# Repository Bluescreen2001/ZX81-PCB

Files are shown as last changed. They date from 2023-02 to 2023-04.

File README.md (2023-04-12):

# ZX81-PCB

Recreation of the original ZX81 Issue1 PCB with rounded traces, and the WespiNano, a tiny version of the Wespi.

## DISCLAIMER:

This is for personal use only. You may not sell this design without contacting me.

## Description:

The Sinclair ZX81 was one of the first home computers. There are several PCB versions out there, but the film for the first version was created 
manually with clear foil and stickers and pen. This first version (Issue One) is rare but it is "the original" with non CAD like rounded traces.

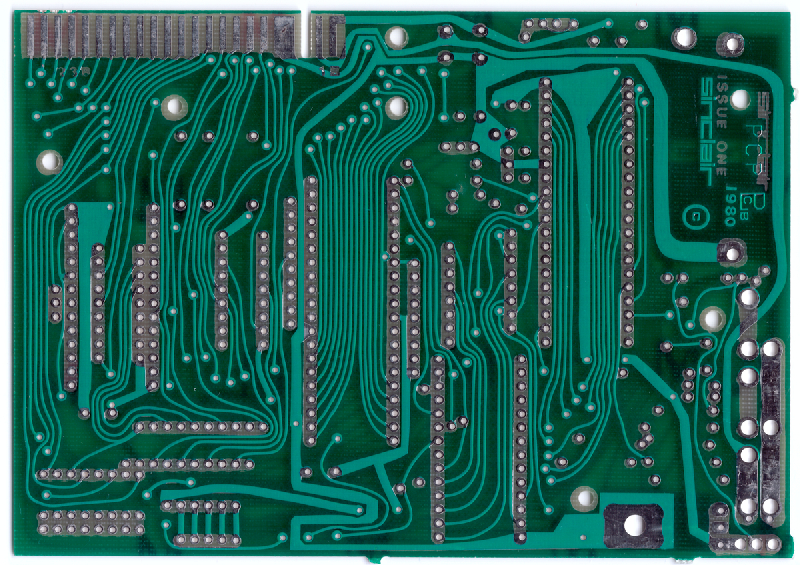
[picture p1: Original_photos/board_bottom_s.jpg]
Original PCB


One day some people from the German Sinclair [ZX81 forum](https://forum.tlienhard.com) diskussed how this PCB can be recreated.
So I took a photo from front and back side of the PCB with a scanner, put this as a background images in my CAD application and redraw all the traces. 
The resulting DXF file was then imported into EAGLE and than mapped to an EAGLE schematic, so I get a consistent EAGLE project. After some fine tuning 
I got a PCB design which was nearly like the original.

After some diskussions we decided to create a slightly altered version with some "modern" features. See the following chapter ...

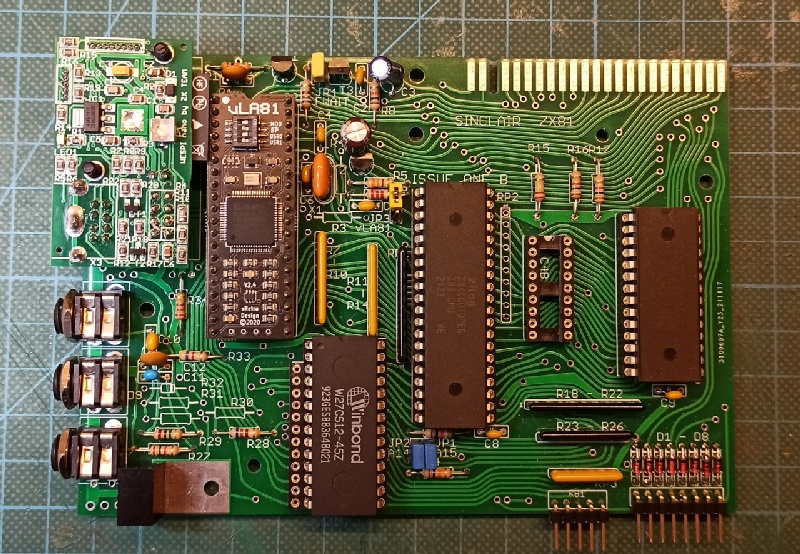
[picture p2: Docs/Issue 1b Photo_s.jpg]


## Versions:

### Issue 1:

This is the most authentic version. Nearly like the original with nothing changed at all:

- modulator
- old EPROM
- single resistors instead of SIL arrays

### Issue 1a:

Like Issue 1 above, but a slightly improved silkscreen. Some single resistors are replaced with SIL arrays, but no changes to the PCB traces, 
besides some cosmetic corrections

### Issue 1b:

Some functional addons:

- added connector for a small VideoOut board "under" the modulator footprint. You can omit the modulator and place this connector to add the 
  videoOut board to get an video out connector instead of the RF output. You can also add a WespNano (see below) to get WiFi, Storage and VGA.
- added footprint for a "modern" EPROM with two jumpers to select the page you like.
- added "Fast Wait" logic with a disable jumper
- added a jumper for vLA81 support. This routes the OSC pin of the ULA to A13 of the RAM, so you can use ...
- modern CMOS RAM up to 32 kB, supported by the vLA81

### Issue 1c:

- added an reset button
- added a second mounting hole for the VideoOut board for better stability.

## Addons

### VideoOut

A small addon board fitting onto Issue 1b and higher that features a buffered composite video out cinch connector

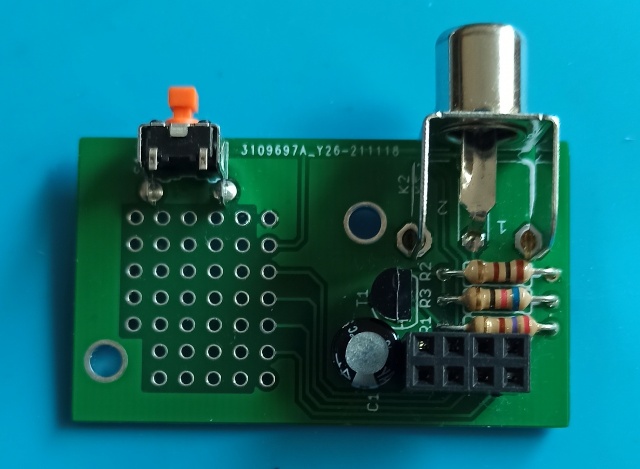
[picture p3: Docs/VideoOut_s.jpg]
VideoOut


### Wespi-Nano

This is a tiny version of the Wespi project from the [ZX81 forum](https://forum.tlienhard.com). It uses an esp32 to scan the video signal to create 
a VGA or TFT video signal. Also it can send files to the ZX's tape input using a fastload mechanism. The files came from the esp's onboard flash memory 
which can be populated using a web interface from your PC or mobile. Loading is initiated by an onscreen menu on the ZX81 screen via load command.

## Hints:
In every subdirectory you find a *_Gerbers.zip. This are the files you need to create the PCB by any PCB manufacturer like JLCPCB.
In the doc directory are some photos and a nice German manual.

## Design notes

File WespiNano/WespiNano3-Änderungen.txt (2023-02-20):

R1 : Neuer Wert, 1,5k statt 180kOhm, Vorwiderstand für LED
C1 : Neuer Wert, 100nF statt 1uF, Eingangskondensator für Video, hat aber wohl nichts gebracht
R4 : Neuer Wert, 160 Ohm statt 470 Ohm, weiß nicht mehr obs was gebracht hat. Ich denke, das Wichtigste ist folgender Punkt: 

Auf Zeddyboard: Pin3 des Wespisteckers statt an ULA Pin 20 an die TapeIn Buchse anschliessen. Dazu eine Leiterbahn unterbrechen und neu anschliessen. Alternativ auf Wespiboard R4 auslöten und anders herum einlöten, so dass der obere Pin in der Luft hängt. Diesen dann mit TapeIn Buchse verbinden.

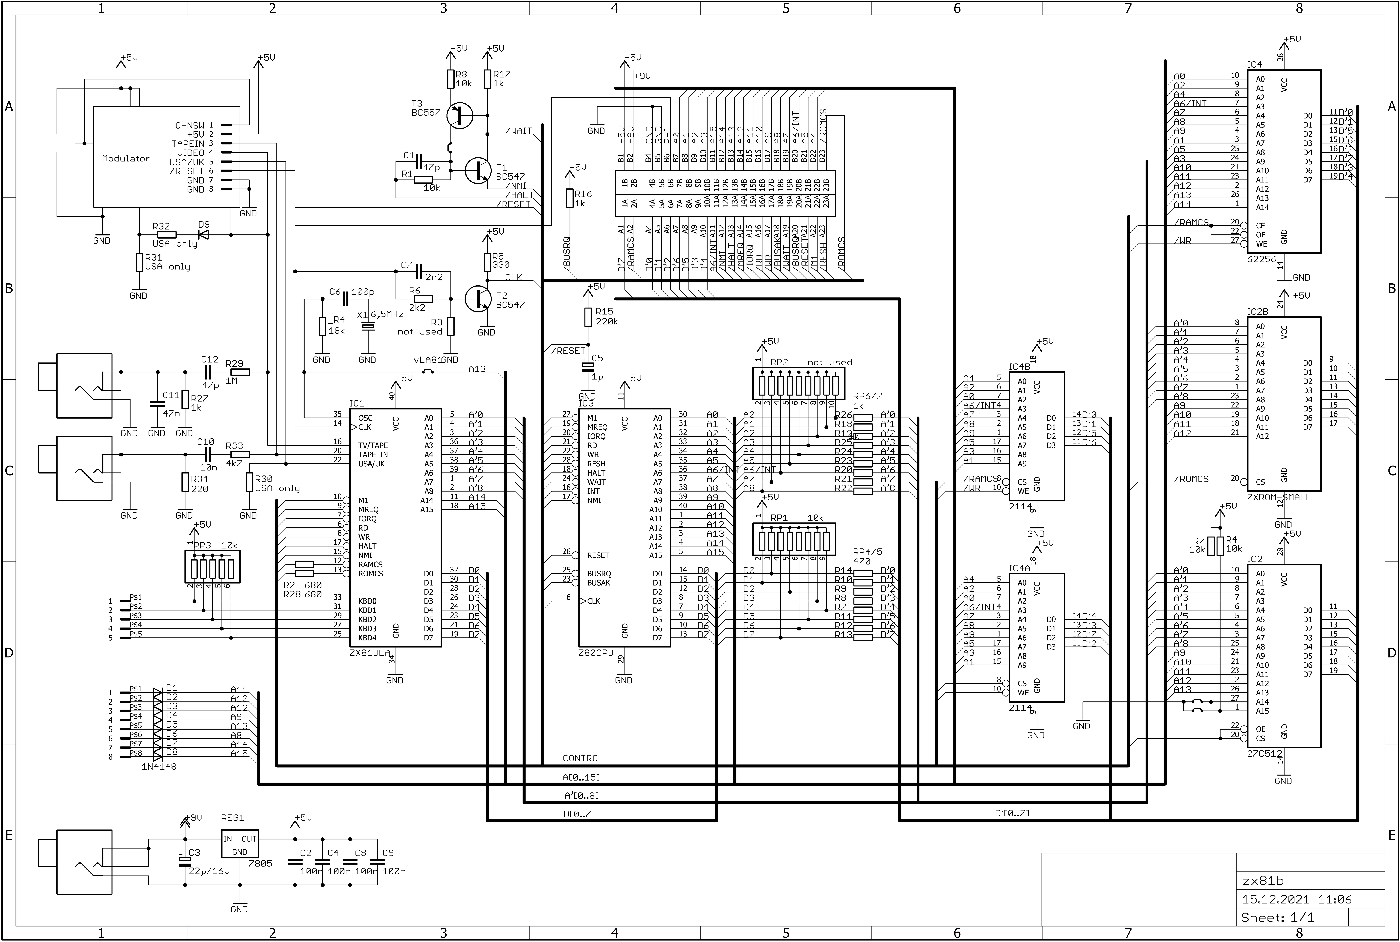
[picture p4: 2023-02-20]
ZX81b/zx81b-schematic.png

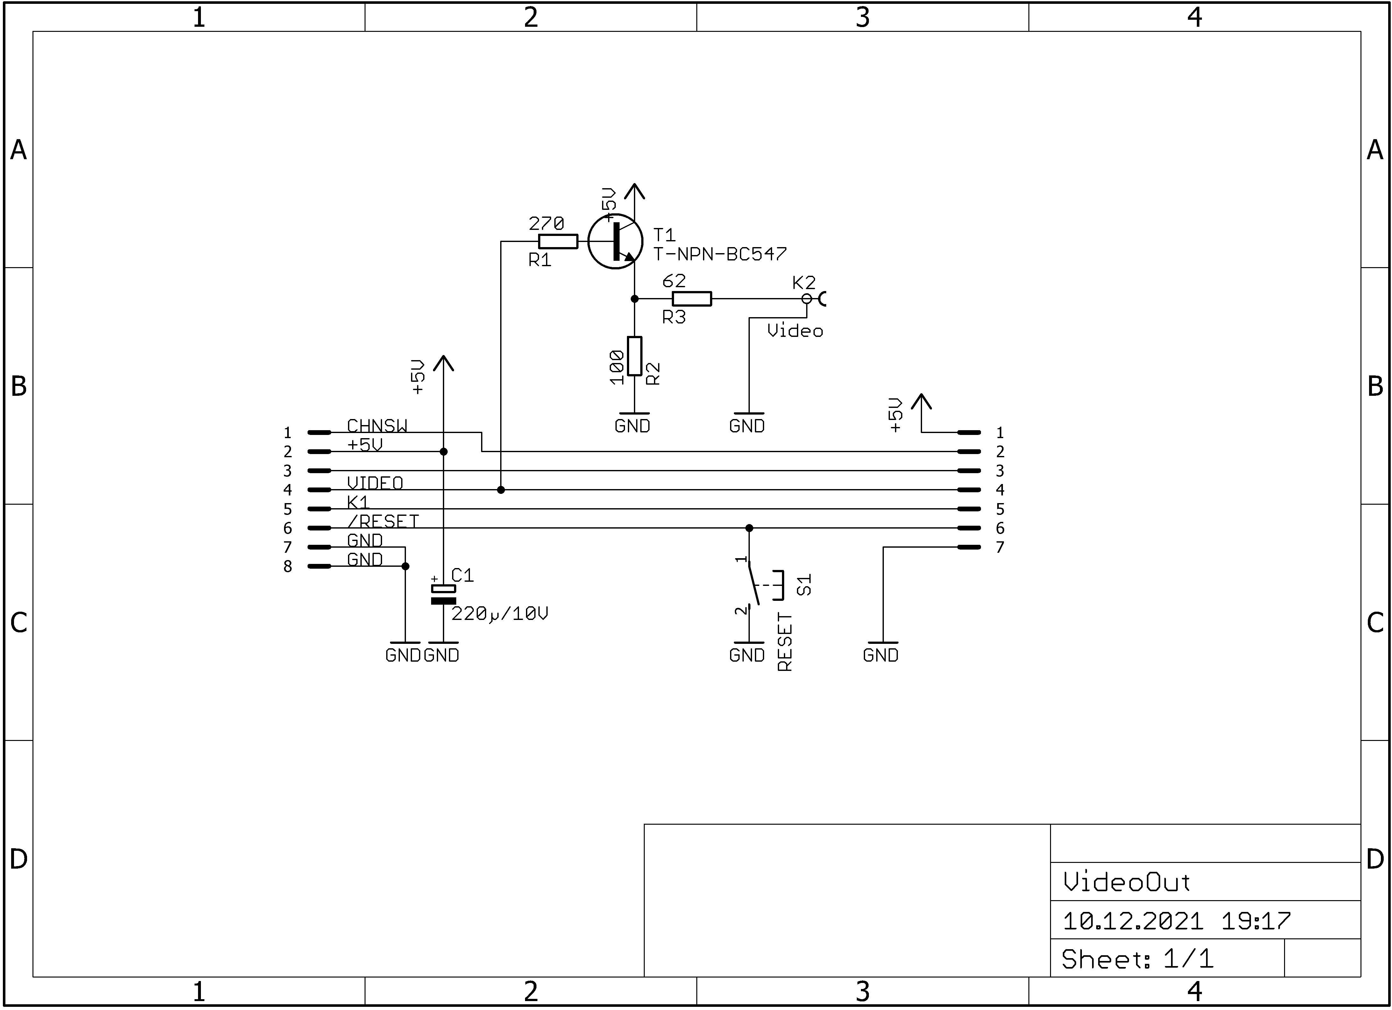
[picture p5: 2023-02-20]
VideoOut/VideoOut-schematic.png

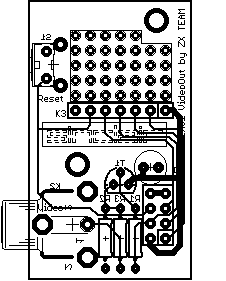
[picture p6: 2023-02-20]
VideoOut/VideoOut-pcb.png

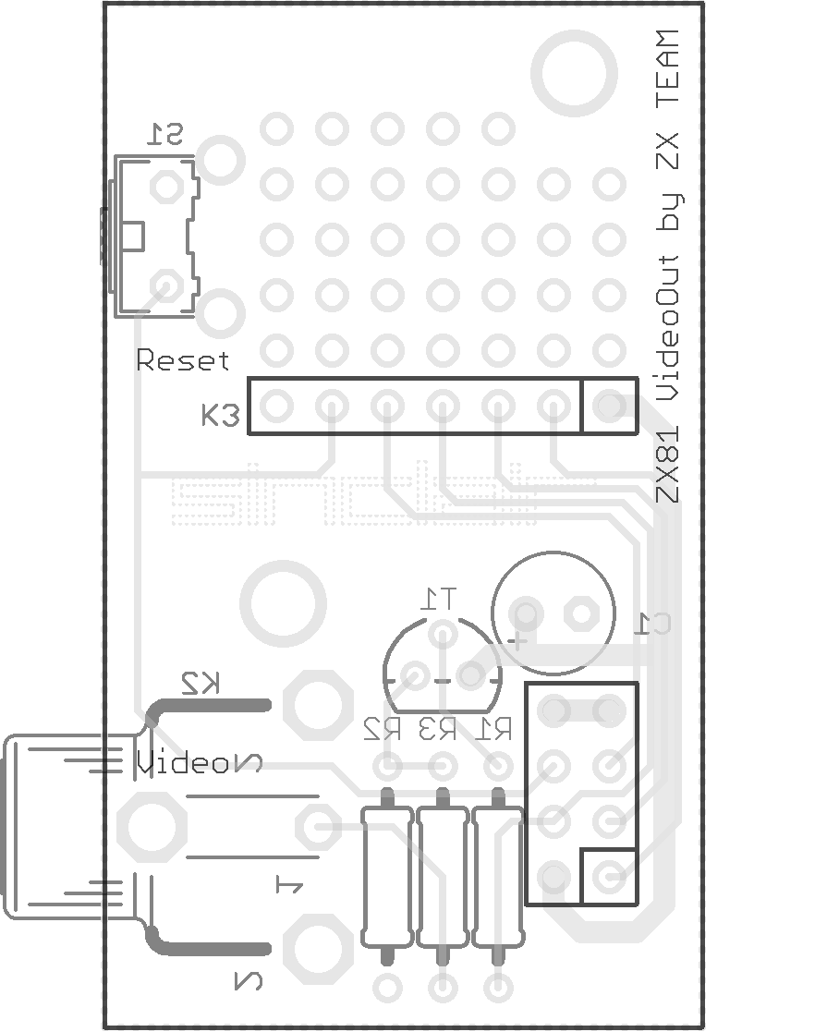
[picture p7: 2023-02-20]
VideoOut/VideoOut-pcb-color.png

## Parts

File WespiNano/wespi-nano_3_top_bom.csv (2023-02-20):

Comment | Designator | Footprint | LCSC Part #
 | LED1 | SML0805
 | T1 | SOT23-BEC
1N4148 | D1 | SOD-123_MINI-SMA
1k5 | P1 | 3223G
1µ | C1 C2 C4 C5 C6 | C0805
4 7µ | C3 | 153CLV-0405
4k7 | R3 | R0805
10k | R19 | R0805
27k | R12 | R0805
39 | R18 | R0805
62 | R21 | R0805
100 | R8 R9 R22 | R0805
100n | C7 | C0805
180k | R1 R2 | R0805
270 | R5 R6 R7 R20 | R0805
470 | R4 R10 R11 R13 R14 R15 R16 R17 | R0805
1117-3.3V | IC1 | SOT223
BSS123 | T2 | SOT23

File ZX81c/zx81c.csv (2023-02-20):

Part | Value | Device | Package | Description
C1 | 47p | C | C025-025X050
C2 | 100n | C | C025-025X050
C3 | 22µ/16V | CPOLE5-5 | E5-5
C4 | 100n | C | C025-025X050
C5 | 1µ | CPOLE3,8-5 | E3,8-5
C6 | 100p | C | C025-025X050
C7 | 2n2 | C | C025-025X050
C8 | 100n | C | C025-025X050
C9 | 100n | C | C025-025X050
C10 | 10n | C | C025-025X050
C11 | 47n | C | C025-025X050
C12 | 47p | C | C025-025X050
D1 | 1N4148 | DIODEDTR | D-TR-10
D2 | 1N4148 | DIODEDTR | D-TR-10
D3 | 1N4148 | DIODEDTR | D-TR-10
D4 | 1N4148 | DIODEDTR | D-TR-10
D5 | 1N4148 | DIODEDTR | D-TR-10
D6 | 1N4148 | DIODEDTR | D-TR-10
D7 | 1N4148 | DIODEDTR | D-TR-10
D8 | 1N4148 | DIODEDTR | D-TR-10
D9 |  | DIODED15 | D15
IC1 | ZX81ULA | ZX81ULA | DIL40
IC2 | 27C512 | 27C512 | DIL28
IC2B | ZXROM-SMALL | ZXROM-SMALL | DIL24
IC3 | Z80CPU | Z80CPU | DIL40
IC4 | 62256 | 62256 | DIL28
IC4A | 2114 | 2114 | DIL18
IC4B | 2114 | 2114 | DIL18
JP1 | JUMPER | JUMPER | JUMPER
JP2 | JUMPER | JUMPER | JUMPER
JP3 | JUMPER | JUMPER | JUMPER
JP4 | JUMPER | JUMPER | JUMPER
K1 | ZX81CONN | ZX81CONN | ZX81CON
K2 | MIC | ZXKLINKE | ZXKLINKE
K3 | EAR | ZXKLINKE | ZXKLINKE
K4 | DCIN | ZXKLINKE | ZXKLINKE
K5 | PINHEAD-2X4 | PINHEAD-2X4 | PINHEAD2X4
KB1 | ZXKBD5CON | ZXKBD5CON | ZXKDB5
KB2 | ZXKBD8CON | ZXKBD8CON | ZXKBD8
R1 | 10k | RR207/12 | R207/12
R2 | 680 | RR207/12 | R207/12
R3 | not used | RR207/12 | R207/12
R4 | 10k | RR207/12 | R207/12
R5 | 330 | RR207/12 | R207/12
R6 | 2k2 | RR207/12 | R207/12
R7 | 10k | RR207/12 | R207/12
R8 | 10k | RR207/12 | R207/12
R15 | 220k | RR207/12 | R207/12
R16 | 1k | RR207/12 | R207/12
R17 | 1k | RR207/12 | R207/12
R27 | 1k | RR207/12 | R207/12
R28 | 680 | RR207/12 | R207/12
R29 | 1M | RR207/12 | R207/12
R30 | USA only | RR207/12 | R207/12
R31 | USA only | RR207/12 | R207/12
R32 | USA only | RR207/12 | R207/12
R33 | 4k7 | RR207/12 | R207/12
R34 | 220 | RR207/12 | R207/12
REG1 | 7805 | 78XX | 78XXL
RP1 | not used | RSIL8 | SIL9
RP2 | 10k | RSIL9 | SIL10
RP3 | 10k | RSIL5 | SIL6
RP4 | 470 | RSILP4 | SIL8P
RP5 | 470 | RSILP4 | SIL8P
RP6 | 1k | RSILP4 | SIL8P
RP7 | 1k | RSILP5 | SIL10P
T1 | BC547 | T-NPN-BC547 | TO92
T2 | BC547 | T-NPN-BC547 | TO92
T3 | BC557 | T-PNP-BC557 | TO92
X1 | 6,5MHz | CRYSTAL | HC49
_R4 | 18k | RR207/12 | R207/12

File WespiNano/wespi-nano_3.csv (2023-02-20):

Part | Value | Device | Package | Description | MF | MPN | OC_FARNELL | OC_NEWARK
C1 | 1µ | C-EUC0805 | C0805 | CAPACITOR, European symbol
C2 | 1µ | C-EUC0805 | C0805 | CAPACITOR, European symbol
C3 | 4,7µ | CPOL-EU153CLV-0405 | 153CLV-0405 | POLARIZED CAPACITOR, European symbol
C4 | 1µ | C-EUC0805 | C0805 | CAPACITOR, European symbol
C5 | 1µ | C-EUC0805 | C0805 | CAPACITOR, European symbol
C6 | 1µ | C-EUC0805 | C0805 | CAPACITOR, European symbol
C7 | 100n | C-EUC0805 | C0805 | CAPACITOR, European symbol
C8 | 220µ/10V | CPOL-EUE2.5-6 | E2,5-6 | POLARIZED CAPACITOR, European symbol
D1 | 1N4148 | CGRM4001-G | SOD-123_MINI-SMA | Molded plasitc,JEDEC SOD-123/Mini SMA
IC1 | REG1117 | REG1117 | SOT223
K6 | PINHEAD-2X4 | PINHEAD-2X4 | PINHEAD2X4
LED1 |  | LEDSML0805 | SML0805 | LED
P1 | 1k5 | PC25 | PC25 | VITROHM POTENTIOMETER | CLAROSTAT | 308NPC25KS | 1440998 | 03F7518
Q1 | BSS123 | BSS123 | SOT23 | N-CHANNEL MOS FET
R1 | 180k | R-EU_R0805 | R0805 | RESISTOR, European symbol
R2 | 180k | R-EU_R0805 | R0805 | RESISTOR, European symbol
R3 | 4k7 | R-EU_R0805 | R0805 | RESISTOR, European symbol
R4 | 470 | R-EU_R0805 | R0805 | RESISTOR, European symbol
R5 | 270 | R-EU_R0805 | R0805 | RESISTOR, European symbol
R6 | 270 | R-EU_R0805 | R0805 | RESISTOR, European symbol
R7 | 270 | R-EU_R0805 | R0805 | RESISTOR, European symbol
R8 | 100 | R-EU_R0805 | R0805 | RESISTOR, European symbol
R9 | 100 | R-EU_R0805 | R0805 | RESISTOR, European symbol
R10 | 470 | R-EU_R0805 | R0805 | RESISTOR, European symbol
R11 | 470 | R-EU_R0805 | R0805 | RESISTOR, European symbol
R12 | 27k | R-EU_R0805 | R0805 | RESISTOR, European symbol
R13 | 470 | R-EU_R0805 | R0805 | RESISTOR, European symbol
R14 | 470 | R-EU_R0805 | R0805 | RESISTOR, European symbol
R15 | 470 | R-EU_R0805 | R0805 | RESISTOR, European symbol
R16 | 470 | R-EU_R0805 | R0805 | RESISTOR, European symbol
R17 | 470 | R-EU_R0805 | R0805 | RESISTOR, European symbol
R18 | 39 | R-EU_R0805 | R0805 | RESISTOR, European symbol
R19 | 10k | R-EU_R0805 | R0805 | RESISTOR, European symbol
R20 | 39 | R-EU_R0805 | R0805 | RESISTOR, European symbol
R21 | 39 | R-EU_R0805 | R0805 | RESISTOR, European symbol
R22 | 39 | R-EU_R0805 | R0805 | RESISTOR, European symbol
T1 |  | BC847-NPN-SOT23-BEC | SOT23-BEC | NPN Transistror
U1 | ESP-WROOM-32 | ESP-WROOM-32 | ESP-WROOM-32
X1 | DISPL | 53047-08 | 53047-08 | CONNECTOR |  | 53047-0810 | 1012258 | 98K9826
X2 | PROG | 53047-05 | 53047-05 | CONNECTOR | MOLEX | 53047-0510 | 9732861 | 38C9901
X3 |  | MINI-DIN-8 | MINI-DIN-8

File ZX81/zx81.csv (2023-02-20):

Part | Value | Device | Package | Description
C1 | 47p | C | C025-025X050
C2 | 100n | C | C025-025X050
C3 | 22µ/16V | CPOLE5-5 | E5-5
C4 | 100n | C | C025-025X050
C5 | 1µ | CPOLE3,8-5 | E3,8-5
C6 |  | C | C025-025X050
C7 | 47p | C | C025-025X050
C8 | 100n | C | C025-025X050
C9 | 100n | C | C025-025X050
C10 | 10n | C | C025-025X050
C11 | 47n | C | C025-025X050
C12 | 47p | C | C025-025X050
D1 |  | DIODED10 | D10
D2 |  | DIODED10 | D10
D3 |  | DIODED10 | D10
D4 |  | DIODED10 | D10
D5 |  | DIODED10 | D10
D6 |  | DIODED10 | D10
D7 |  | DIODED10 | D10
D8 |  | DIODED10 | D10
D9 |  | DIODED15 | D15
IC1 | ZX81ULA | ZX81ULA | DIL40
IC2 | 2764 | 2764 | DIL24
IC3 | Z80CPU | Z80CPU | DIL40
IC4 | 4816 | 4816 | DIL28
IC4A | 2114 | 2114 | DIL18
IC4B | 2114 | 2114 | DIL18
K1 | ZX81CONN | ZX81CONN | ZX81CON
K2 | MIC | ZXKLINKE | ZXKLINKE
K3 | EAR | ZXKLINKE | ZXKLINKE
K4 | DCIN | ZXKLINKE | ZXKLINKE
KB1 | ZXKBD5CON | ZXKBD5CON | ZXKDB5
KB2 | ZXKBD8CON | ZXKBD8CON | ZXKBD8
R1 | 10k | RR207/12 | R207/12
R2 | 680 | RR207/12 | R207/12
R3 | not used | RR207/12 | R207/12
R5 | 330 | RR207/12 | R207/12
R6 | 2k2 | RR207/12 | R207/12
R7 | 470 | RRV | RV
R8 | 470 | RRV | RV
R9 | 470 | RRV | RV
R10 | 470 | RRV | RV
R11 | 470 | RRV | RV
R12 | 470 | RRV | RV
R13 | 470 | RRV | RV
R14 | 470 | RRV | RV
R15 | 220k | RR207/12 | R207/12
R17 | 1k | RR207/12 | R207/12
R18 | 1k | RRV | RV
R19 | 1k | RRV | RV
R20 | 1k | RRV | RV
R21 | 1k | RRV | RV
R22 | 1k | RRV | RV
R23 | 1k | RRV | RV
R24 | 1k | RRV | RV
R25 | 1k | RRV | RV
R26 | 1k | RRV | RV
R27 | 1k | RR207/12 | R207/12
R28 | 680 | RR207/12 | R207/12
R29 | 1M | RR207/12 | R207/12
R30 |  | RR207/12 | R207/12
R31 |  | RR207/12 | R207/12
R32 |  | RR207/12 | R207/12
R33 | 4k7 | RR207/12 | R207/12
R34 | 220 | RR207/12 | R207/12
REG1 | 7805 | 78XX | 78XXL
RP1 | not used | RSIL8 | SIL9
RP2 | 10k | RSIL9 | SIL10
RP3 | RSIL5 | RSIL5 | SIL6
T1 |  | T-NPN-ZTX313TO92FLAT | TO92FLAT
T2 |  | T-NPN-ZTX313TO92FLAT | TO92FLAT
X1 | 6,5MHz | CRYSTAL | HC49
_R4 | 18k | RR207/12 | R207/12
_R16 |  | RR207/12 | R207/12

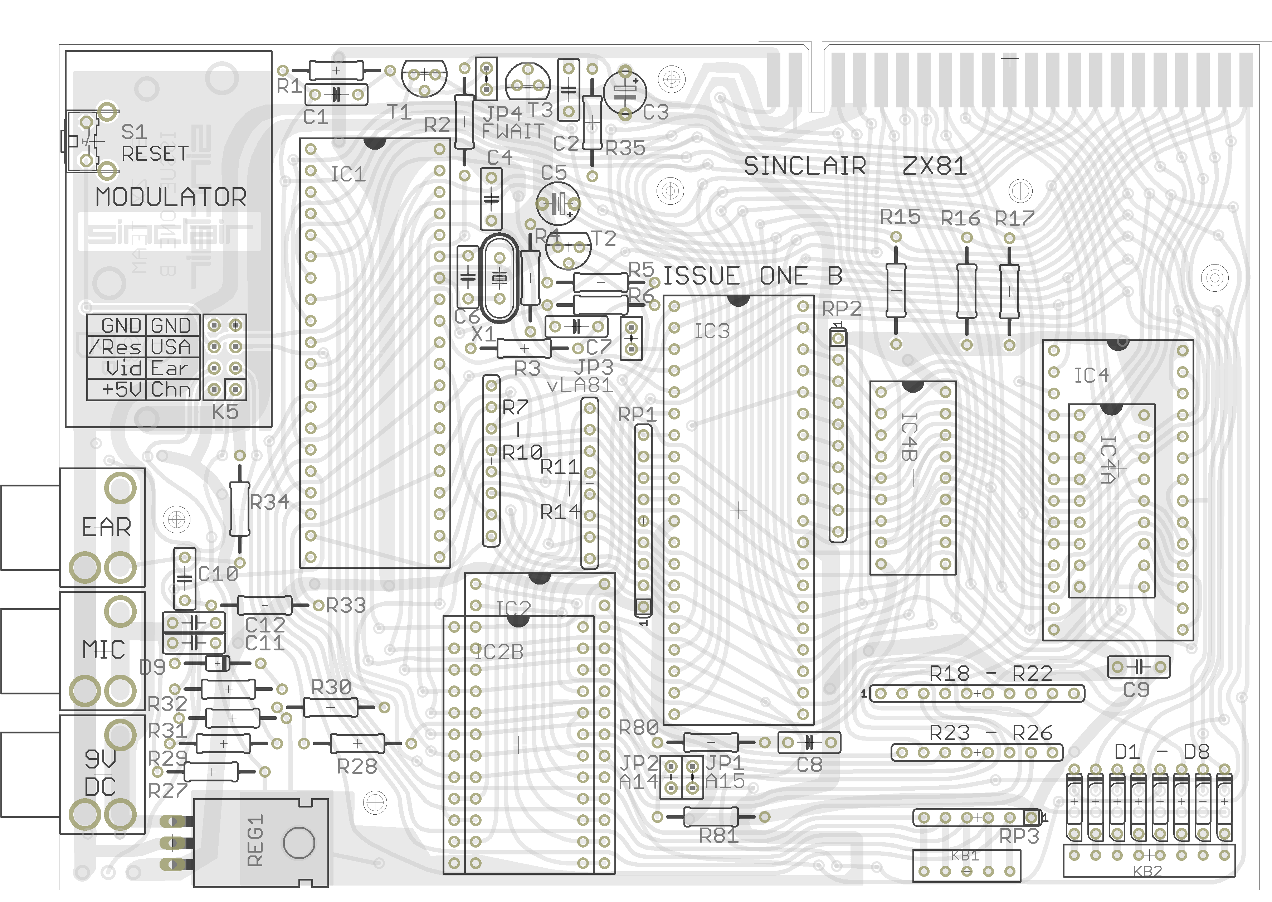
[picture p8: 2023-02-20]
ZX81c/zx81c-pcb-parts.png

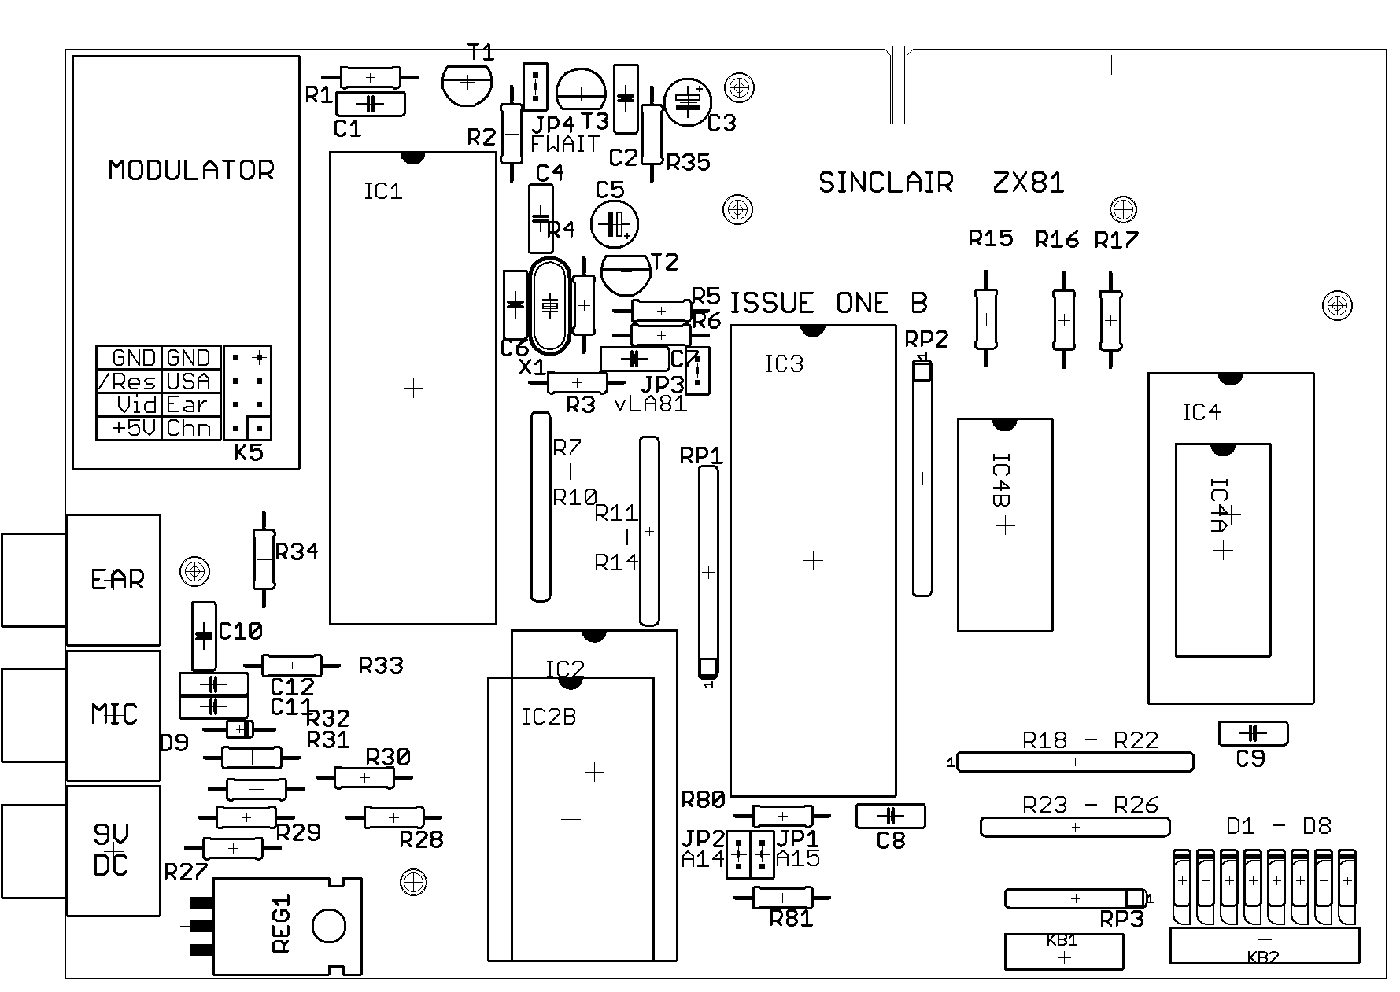
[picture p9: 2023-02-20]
ZX81b/zx81b-pcb-parts.png

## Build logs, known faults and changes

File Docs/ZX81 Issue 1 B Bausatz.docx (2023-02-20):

# ZX81 Issue 1 B Bausatz

Der ZX81 war einer der ersten Homecomputer der 1981 von Sir Cleve Sinclair auf den Markt gebracht wurde. Damals gab es die Geräte als Bausatz zu kaufen. Das Gerät war zu seiner Zeit preislich unschlagbar, was aber durchaus mit einigen technischen Einschränkungen verbunden war. So hatte der ZX81 damals zunächst nur 1kB RAM. Das war kaum mehr als sein vollgeschriebener Bildschirmbereich.

Aber gerade diese Einschränkungen veranlassten viele Benutzer zu geradezu akrobatischen Programmiertricks um RAM zu sparen und dennoch spannende Programme zu schreiben.

Selbst heute gibt es ein recht aktive Community. Es gibt viele originale ZX81 die heute noch laufen, aber es gibt auch viele Nachbauten. Diese haben meist umfangreichere Hardware, so ist inzwischen die 32 kB RAM Erweiterung praktisch immer vorhanden.

Die originale ZX81 Issue 1 Platine ist dennoch etwas Besonderes. Im Gegensatz zu den Nachfolgern ist sie noch per Hand gezeichnet worden. Mit Klebesymbolen auf Folie. Diese Originale sind natürlich längst nicht mehr verfügbar um die Platine nachzufertigen.

Und genau dies will ich mit dieser Issue 1B tun. Ich möchte das geschwungene Layout des Originals beibehalten und dennoch eine reproduzierbare Platine erzeugen. Dazu habe ich Fotos der Originalplatine digitalisiert und in mühsamer Kleinarbeit in das Layoutprogramm Eagle importiert und mit dem Schaltplan verknüpft und anschließend etwas nachbearbeitet. Und das sollte es eigentlich sein, die Issue 1 A war geboren.

Dann kamen aber Probleme auf mit der Beschaffbarkeit von Bauteilen und Anschlüssen. So sind die alten RAMs und ROMs kaum noch zu beschaffen. Und 32kB will man ja nun doch haben. Und einen TV als Monitor mit HF Eingang gibt es auch praktisch nicht mehr. Also habe ich die Platine vorsichtig erweitert, ohne den optischen Gesamteindruck zu stören. Das Ergebnis ist die Issue 1 B, die hier vorliegt. Diese hat gegenüber dem Original folgende Ergänzungen:

1. Anstelle des Modulators kann ein 8-poliger Pfostenstecker eingelötet werden. Auf diesem liegen alle Anschlüsse, die für Videoausgabe und Audioeingabe erforderlich sind, zusätzlich zu einer Zusatzleitung zur ULA (das ist das spezielle Hauptchip des ZX81). Auf diesen Pfostenstecker kann ein VideoOut Modul gesteckt werden. Dazu später mehr.
2. Alternativ zu den zwei 1kB RAMs kann nun ein 32kB CMOS RAM (62256) eingesteckt werden. Nutzt man dann auch statt der Original-ULA die vLA ZX81 stehen einem 32kB internes RAM zur Verfügung.
3. Statt des Original-ROMs kann man auch ein 27c512 EEPROM bestücken. Hier hat man dann vier 16kB ROM Blöcke zur Auswahl, die per Jumper ausgewählt werden können. Das Original-ROM hat nur 8kB, man kann also auch ein erweitertes ROM BASIC nutzen
4. Die NoWait Logik ist enthalten. Der Original ZX81 hat beim Zugriff auf RAM teilweise Wait-Zyklen erzeugt. Diese Logik unterdrückt diese an Stellen wo sie nicht nötig sind, was zur einer gewissen Performancesteigerung führt.
5. Die alten Transistoren sind schwer zu beschaffen. Die Bauteilwerte drumherum wurden angepasst, so dass es mit einem heute gängigen BC547 bzw. BC557 funktioniert.

Nun genug des Vorgeplänkels, nun geht’s ans Zusammenbauen.

## Aufbauhinweise

Wie schon besprochen, sind verschiedene Bestückungsvarianten möglich:

1. RAM, 1kB oder 32kB Die alten 1kB RAMs kommen an die Stellen IC4A und IC4B, alternativ kann man das 32kB RAM in den IC4 Sockel stecken. Es können auch beide Sockel bestückt werden um flexibel zu sein. Dazu muss man den Mittelsteg des IC4 Sockels entfernen, damit der IC4A Sockel hinein passt.
2. ROM, Original oder EEPROM Das Original-ROM kommt in den 24 poligen Sockel IC2B, das EEPROM vom Typ 27C512 kommt in den 28 poligen Sockel IC2. Will man beide Sockel bestücken, muß auch hier an den Sockeln herumgeschnitten werden, oder man nimmt gleich „Präzisionssockelleisten“ (nicht im Lieferumfang)
3. Echte ULA oder vLA ZX81 im Sockel IC1. Letztere ist ein Nachbau der Original-ULA auf Basis eines CPLDs. Diese ist leichter Beschaffbar als das Original und schöpft auch das RAM voll aus. Diese Variante wird empfohlen. Um die vLA Funktionen vollständig zu nutzen ist der Jumper JP3 zu setzen. Bei einer echten ULA ist dieser zu entfernen, sonst läuft der CPU Takt nicht an.
4. NoWait Logik nutzen oder nicht. Die NoWait Logik besteht aus den Teilen R8, R17 und T3. Braucht man sie nicht, können diese Teile weggelassen werden. Hat man sie aufgebaut und möchte sie aktivieren muss der Jumper JP4 gesetzt werden.
5. Modulator oder VideoOut Modul. Man kann in die Platine nach wie vor einen Modulator einlöten,, aber das wird wohl kaum jemand wollen, weil es keine Fernseher mit Antennenanschluss mehr gibt. Statt dessen kann an dessen Stelle der Pfostenstecker K5 bestückt werden. Auf diesen kann dann später das VideoOut Modul gesteckt werden, oder ein WespiNano oder (to be continued)

Ansonsten ist der Aufbau standard. Ich empfehle, zunächst die IC Sockel zu bestücken. Man kann dann die Platine noch bequem auf den Kopf legen um die Sockel am Herausfallen zu hindern und diese dann verlöten. Danach dann die flachen Teile wie Widerstände und Widerstandsarrays. Die Widerstandsarrays RP4..7 sind Einzelwiderstände, die Polarität ist hier egal. Die anderen Array haben einen Punkt beim Pin eins, der mit der Markierung auf der Platine übereinstimmen muss. Als nächstes kommen die Kondensatoren, zum Schluss dann die Buchsen und der Spannungsregler.

Danach würde ich zunächst die Platine mal ohne ICs in Betrieb nehmen und prüfen ob magischer Rauch aufsteigt. Mit einem Multimeter dann die Versorgungsspannung überprüfen. Z.B. an der ULA Pin 34 und Pin 40. Hier sollten 5V anstehen. Ist bis dahin alles in Ordnung, können die ICs gesteckt werden.

## Kein Bild, kein Ton, ich komme schon

Wo schließe ich nun den Monitor an? Wenn ein Modulator verwendet wurde dürft ihr Opas alten Fernseher vom Dachboden kramen und diesen an den Antennenanschluss des Modulators anschliessen. Oder ihr bestückt noch eben das beiliegende Winzigplatinchen des VideoOut Modul. Lasst dabei erstmal die Steckerleiste weg.

Montiert dann die Abstandshalter in die Haupplatine, steckt die Buchsenleiste auf die Hauptplatine und darauf dann die VideoOutplatine. Dies am besten auch gleich mit den Abstandsbolzen verschrauben. Jetzt verlötet ihr die Pfostenbuchse. Sie wird so etwas erhöht festgelötet um den Abstand zur Hauptplatine auszugleichen. Notfalls wenn sie zu tief sitzt, könnt ihr sie etwas anheben, aber nur soweit, dass die Kontakte noch sicher fassen.

Stöpselt euren Monitor oder TV an die Cinch-Buchse (FBAS oder Composite Eingang am Monitor erforderlich, normalerweise eine gelbe Cinch-Buchse).

Schaltet ein und ihr sollten mit einem freundlichen schwarzen K Cursor auf weißem Grund begrüst werden. Wenn nicht, ganz schlecht. Überprüft alle Lötstellen und schaut ob alle ICs richtig stecken. Wenn alles richtig erscheint hilft wohl nur, messen. Was knifflig werden kann. Schaut mal im tliehardt Forum vorbei. Dort gibt es viele nette ZX81 Freaks die helfen könnten. Oder sprecht mich an: thorsten@trektech.de.

Viel Erfolg und viel Spaß beim Homecomputing der 80er.

Thorsten

## Bauteilliste

ZX81 Issue 1B
Teilenummer | Wert | Beschriftung
C1 | 47p | 470
C2 | 100n | 104
C3 | 22µ/16V | 22µF/16V Polarität beachten !
C4 | 100n | 104
C5 | 1µ | 1µF/63V Polarität beachten !
C6 | 100p | 101
C7 | 2n2 | 222
C8 | 100n | 104
C9 | 100n | 104
C10 | 10n | 103
C11 | 47n | 473
C12 | 47p | 470
D1 | 1N4148 | -
D2 | 1N4148 | -
D3 | 1N4148 | -
D4 | 1N4148 | -
D5 | 1N4148 | -
D6 | 1N4148 | -
D7 | 1N4148 | -
D8 | 1N4148 | -
D9 | not used
IC1 | ZX81ULA
IC2 | 27C512
IC2B | ZXROM-SMALL
IC3 | Z80CPU
IC4 | 62256
IC4A | 2114
IC4B | 2114
JP1 | JUMPER
JP2 | JUMPER
JP3 | JUMPER
JP4 | JUMPER
K1 | ZX81CONN
K2 | MIC
K3 | EAR
K4 | DCIN
K5 | PINHEAD-2X4
KB1 | ZXKBD5CON
KB2 | ZXKBD8CON
R1 | 10k | brau-schwarz-orange
R2 | 680 | blau-grau-braun
R3 | not used
R4 | 18k | brau-blau-orange
R5 | 330 | orange-orange-braun
R6 | 2k2 | rot-rot-rot
R7 | 10k | braun-schwarz-orange
R8 | 10k | braun-schwarz-orange
R15 | 220k | rot-rot-gelb
R16 | 1k | braun-schwarz-rot
R17 | 1k | braun-schwarz-rot
R27 | 1k | braun-schwarz-rot
R28 | 680 | blau-grau-braun
R29 | 1M | braun-schwarz-grün
R30 | USA only
R31 | USA only
R32 | USA only
R33 | 4k7 | gelb-lila-rot
R34 | 220 | rot-rot-braun
R35 | 10k | braun-schwarz-orange
REG1 | Traco 5V/1A
RP1 | 10k | 103
RP2 | Not used
RP3 | 10k | 103
RP4 (R7-R10) | 470 | 471
RP5 (R11-R14) | 470 | 471
RP6 (R23-R26) | 1k | 102
RP7 (R18-R22) | 1k | 102
T1 | BC547
T2 | BC547
T3 | BC557
X1 | 6,5MHz
VideoOut Modul
Teilenummer | Wert | Beschriftung
R1 | 270 | rot-lila-braun
R2 | 100 | braun-schwarz-braun
R3 | 62 | blau-rot-schwarz
K1 | PINHEAD 2x4
K2 | Cinch Buchse
T1 | BC547
C1 | 47µF/16V
S1 | Resettaster

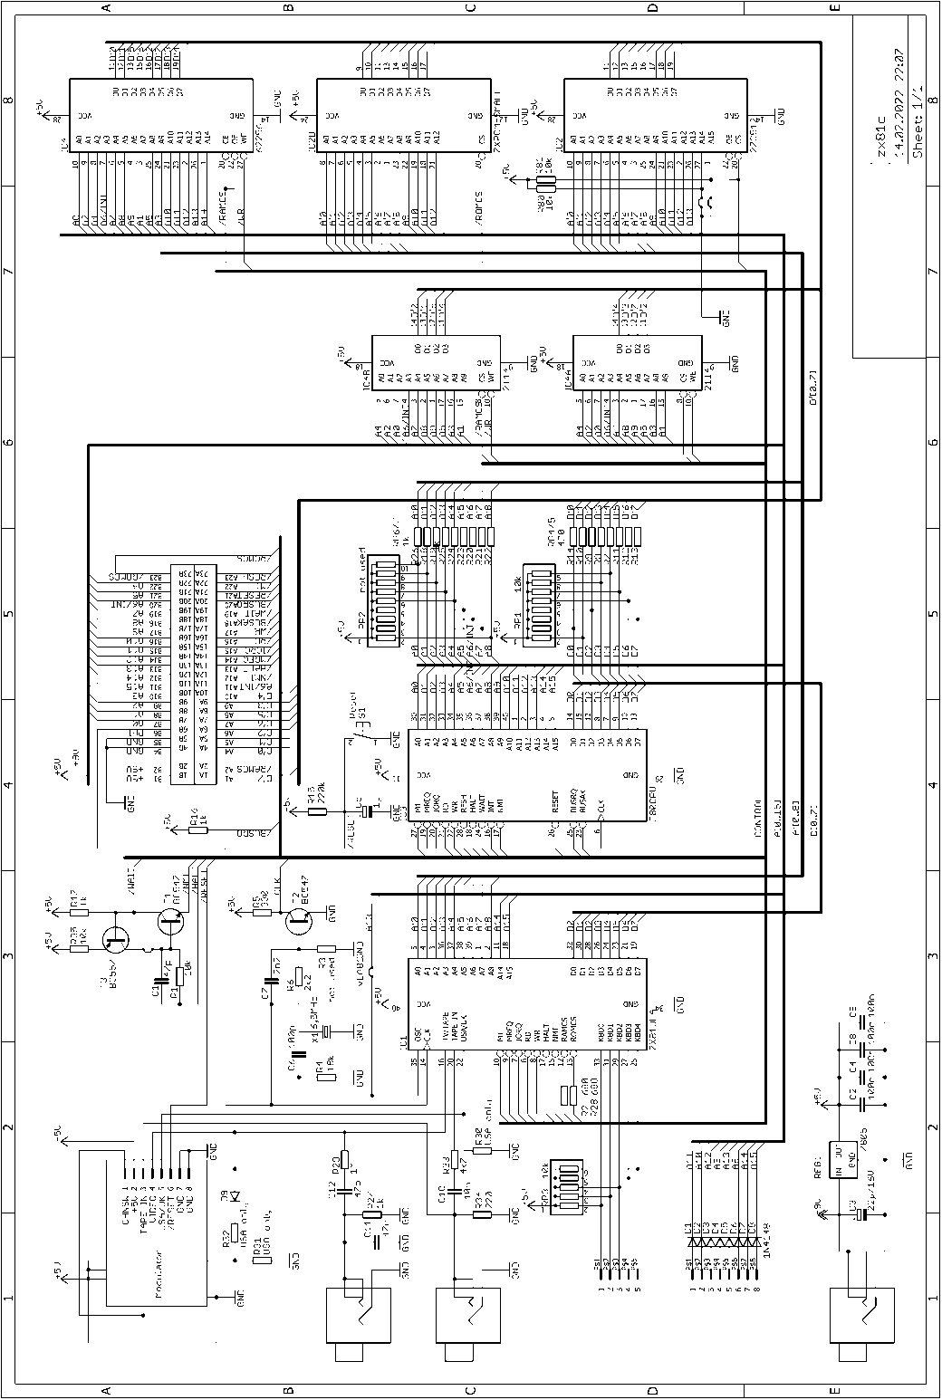
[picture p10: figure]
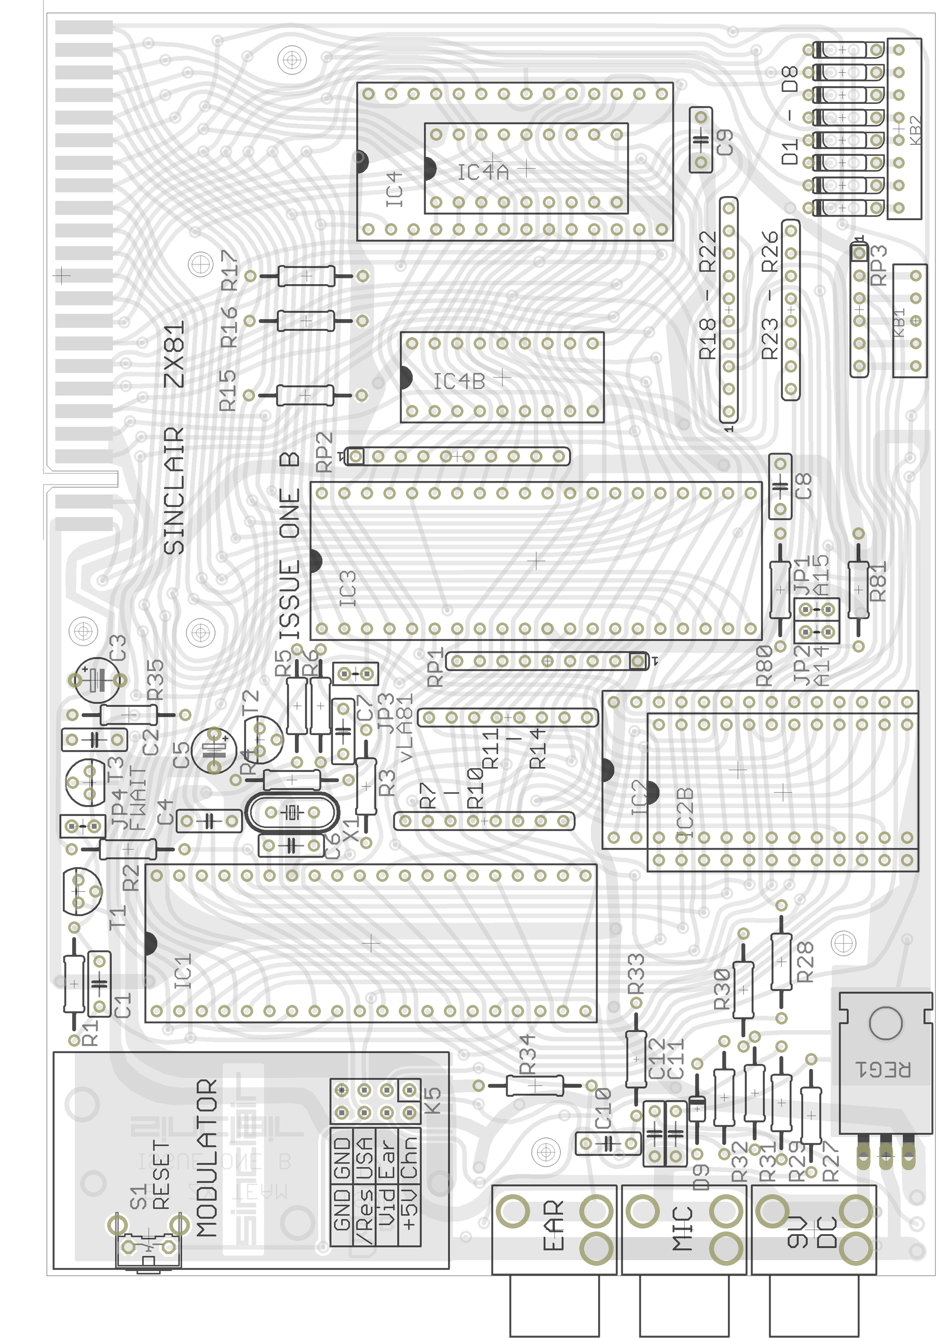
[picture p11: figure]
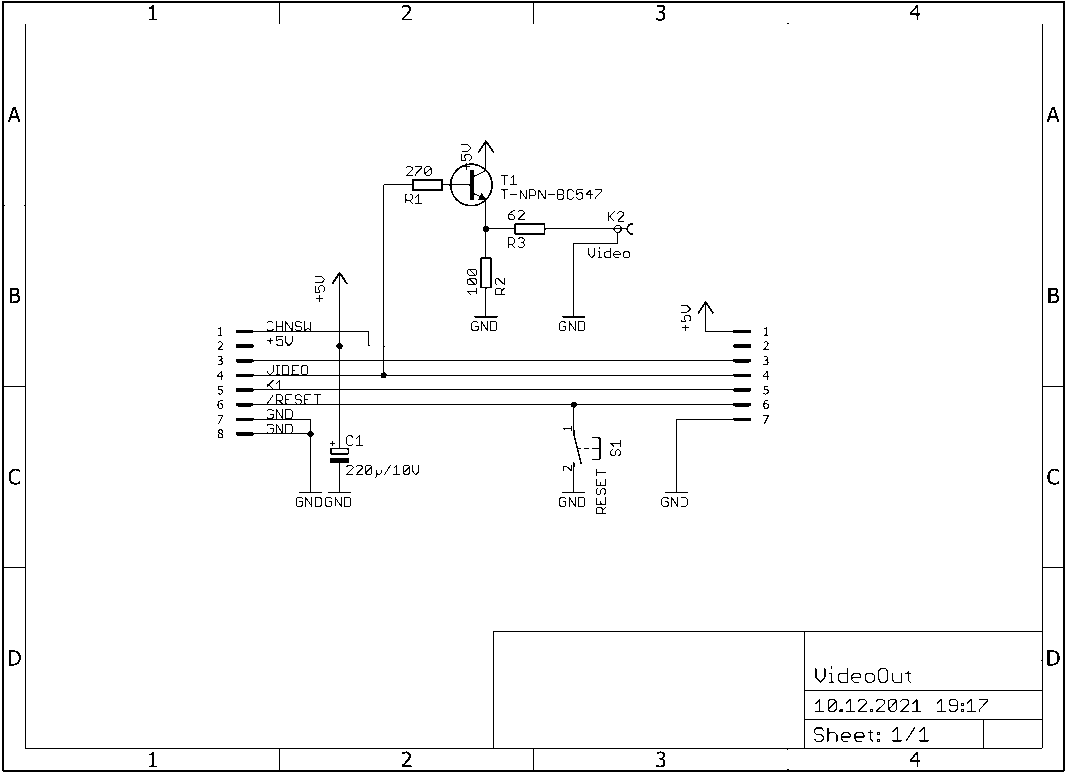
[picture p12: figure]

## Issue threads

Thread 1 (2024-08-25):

Need US versions of modulator and Nano boards

profbbrown, 2024-08-25:
I'd like to build this, but the cutout for the video jack on my US ZX81/Timex-Sinclair 1000 is near the back left of the case. If the boards are simply mounted "upside down", the jack looks like it would line up pretty well, but of course the mounting holes and headers don't.

US versions of the boards would be much appreciated!

Bluescreen2001, 2024-08-25:
On the VideoOut PCB it is easy to swap RCA connector and Reset button. If you need no Reset button you can even mount the RCA on the hole grid area manually. Or take Eagle or Kicad and modify the board.

But WespiNano I think it is impossible because the ESP32 is to big to mount the Video connector left of it. And moving it down collides with the pin header which cannot be move because it has to fit the location on the main PCB.

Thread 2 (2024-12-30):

Versions 1 and 1a of PCBs missing

tomekszafranski, 2024-12-30:
Hi
As far as I was able to go through the repository - there are versions 1b and 1c of pcb available.
Thank you for the effort!

However, it is really sad because the most valueable would be recreation of original pcb.
There are couple of clones available on Internet BUT THERE IS NO ORIGINAL PCB AVAILABLE.

Regards
Tomasz

Closed 2025-03-10.

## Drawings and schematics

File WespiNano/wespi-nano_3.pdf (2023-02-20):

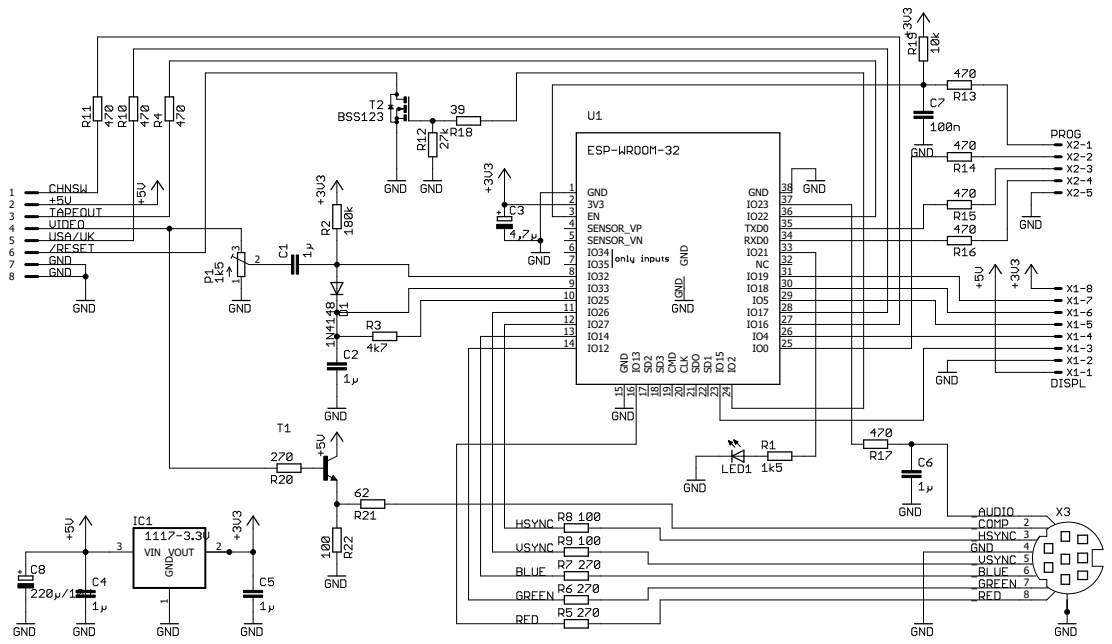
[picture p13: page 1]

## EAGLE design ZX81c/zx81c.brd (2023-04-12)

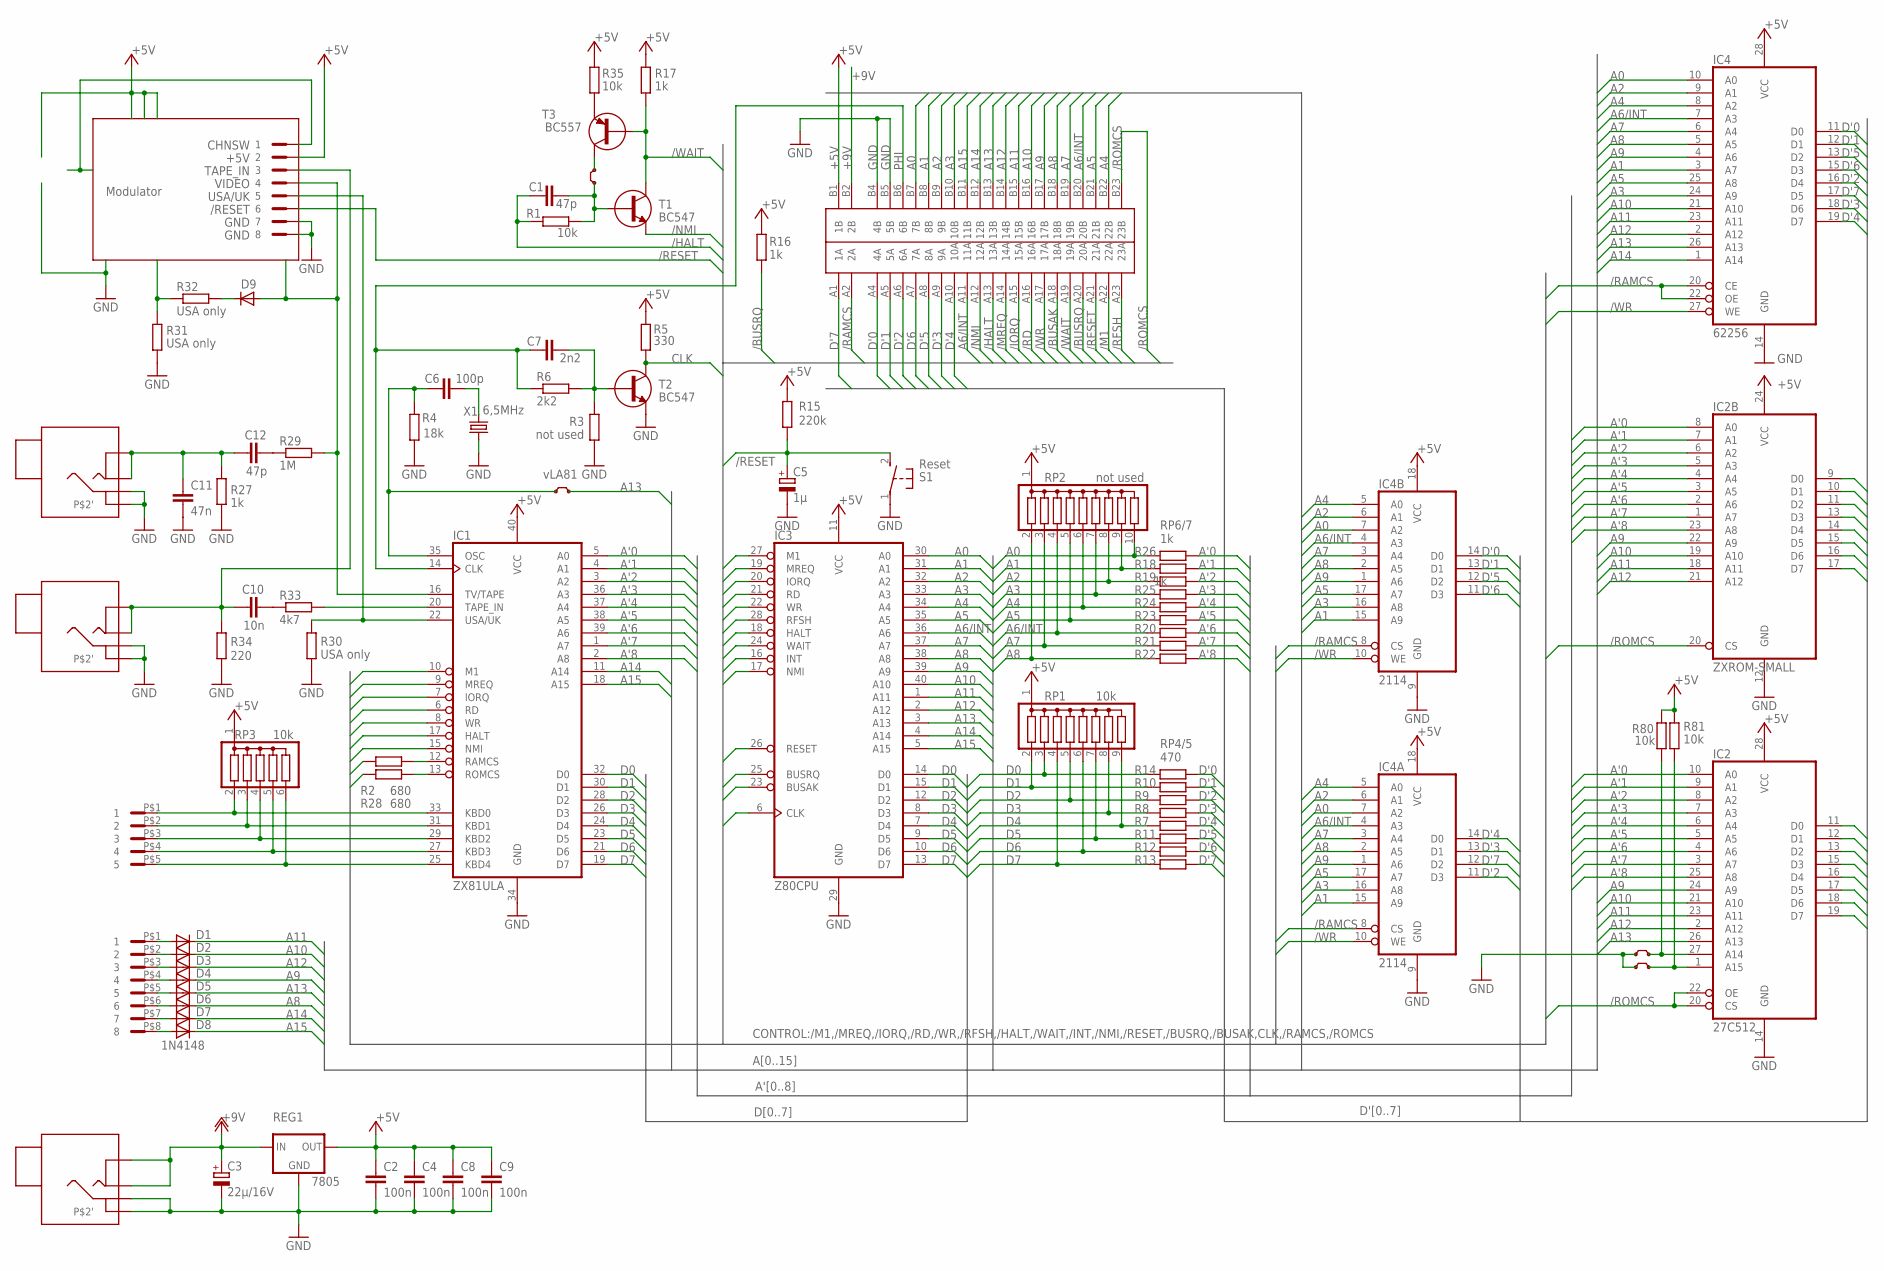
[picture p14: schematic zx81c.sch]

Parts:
C1, C12: 47p; C025-025X050
C2, C4, C8, C9: 100n; C025-025X050
C3: 22µ/16V; E5-5
C5: 1µ; E3,8-5
C6: 100p; C025-025X050
C7: 2n2; C025-025X050
C10: 10n; C025-025X050
C11: 47n; C025-025X050
D1, D2, D3, D4, D5, D6, D7, D8: 1N4148; D-TR-10
D9: DIODED15; D15
IC1: ZX81ULA; DIL40
IC2: 27C512; DIL28
IC2B: ZXROM-SMALL; DIL24
IC3: Z80CPU; DIL40
IC4: 62256; DIL28
IC4A, IC4B: 2114; DIL18
JP1, JP2, JP3, JP4: JUMPER
K1: ZX81CONN; ZX81CON
K2: MIC; ZXKLINKE4POL
K3: EAR; ZXKLINKE4POL
K4: DCIN; ZXKLINKE4POL
K5: PINHEAD-2X4; PINHEAD2X4
KB1: ZXKBD5CON; ZXKDB5
KB2: ZXKBD8CON; ZXKBD8
R1, R35, R80, R81: 10k; R207/12
R2, R28: 680; R207/12
R3: not used; R207/12
R4: 18k; R207/12
R5: 330; R207/12
R6: 2k2; R207/12
R15: 220k; R207/12
R16, R17, R27: 1k; R207/12
R29: 1M; R207/12
R30, R31, R32: USA only; R207/12
R33: 4k7; R207/12
R34: 220; R207/12
REG1: 7805; 78XXL
RP1: 10k; SIL9
RP2: not used; SIL10
RP3: 10k; SIL6
RP4, RP5: 470; SIL8P
RP6: 1k; SIL8P
RP7: 1k; SIL10P
S1: Reset; B3F-31XX
T1, T2: BC547; TO92
T3: BC557; TO92
X1: 6,5MHz; HC49

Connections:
+5V: C2.1, C4.1, C8.1, C9.1, IC1.40 (VCC), IC2.28 (VCC), IC2B.24 (VCC), IC3.11 (VCC), IC4.28 (VCC), IC4A.18 (VCC), IC4B.18 (VCC), K1.B1 (1B), K5.2, R5.2, R15.2, R16.1, R17.2, R35.2, R80.2, R81.2, REG1.OUT, RP1.1, RP2.1, RP3.1
+9V: C3.+, K1.B2 (2B), K4.1, K4.1', REG1.IN
/BUSAK: IC3.23 (BUSAK), K1.A18 (18A)
/BUSRQ: IC3.25 (BUSRQ), K1.A20 (20A), R16.2
/HALT: C1.1, IC1.17 (HALT), IC3.18 (HALT), K1.A13 (13A), R1.1
/IORQ: IC1.7 (IORQ), IC3.20 (IORQ), K1.A15 (15A)
/M1: IC1.10 (M1), IC3.27 (M1), K1.A22 (22A)
/MREQ: IC1.9 (MREQ), IC3.19 (MREQ), K1.A14 (14A)
/NMI: IC1.15 (NMI), IC3.17 (NMI), K1.A12 (12A), T1.E
/RAMCS: IC4.20 (CE), IC4.22 (OE), IC4A.8 (CS), IC4B.8 (CS), K1.A2 (2A), R2.2
/RD: IC1.6 (RD), IC3.21 (RD), K1.A16 (16A)
/RESET: C5.+, IC3.26 (RESET), K1.A21 (21A), K5.6, R15.1, S1.2 (S)
/RFSH: IC3.28 (RFSH), K1.A23 (23A)
/ROMCS: IC2.20 (CS), IC2.22 (OE), IC2B.20 (CS), K1.B23 (23B), R28.2
/WAIT: IC3.24 (WAIT), K1.A19 (19A), R17.1, T1.C, T3.B
/WR: IC1.8 (WR), IC3.22 (WR), IC4.27 (WE), IC4A.10 (WE), IC4B.10 (WE), K1.A17 (17A)
A0: IC3.30 (A0), IC4.10 (A0), IC4A.7 (A2), IC4B.7 (A2), K1.B7 (7B), RP2.10, RP6.8 (2)
A1: IC3.31 (A1), IC4.3 (A7), IC4A.15 (A9), IC4B.15 (A9), K1.B8 (8B), RP2.9, RP7.1
A2: IC3.32 (A2), IC4.9 (A1), IC4A.6 (A1), IC4B.6 (A1), K1.B9 (9B), RP2.8, RP7.4 (2)
A3: IC3.33 (A3), IC4.24 (A9), IC4A.16 (A8), IC4B.16 (A8), K1.B10 (10B), RP2.7, RP6.6 (2)
A4: IC3.34 (A4), IC4.8 (A2), IC4A.5 (A0), IC4B.5 (A0), K1.B22 (22B), RP2.6, RP6.4 (2)
A5: IC3.35 (A5), IC4.25 (A8), IC4A.17 (A7), IC4B.17 (A7), K1.B21 (21B), RP2.5, RP6.2
A6/INT: IC3.16 (INT), IC3.36 (A6), IC4.7 (A3), IC4A.4 (A3), IC4B.4 (A3), K1.A11 (11A), K1.B20 (20B), RP2.4, RP7.6 (2)
A7: IC3.37 (A7), IC4.6 (A4), IC4A.3 (A4), IC4B.3 (A4), K1.B19 (19B), RP2.3, RP7.8 (2)
A8: D6.C, IC3.38 (A8), IC4.5 (A5), IC4A.2 (A5), IC4B.2 (A5), K1.B18 (18B), RP2.2, RP7.10 (2)
A9: D4.C, IC2.24 (A9), IC2B.22 (A9), IC3.39 (A9), IC4.4 (A6), IC4A.1 (A6), IC4B.1 (A6), K1.B17 (17B)
A10: D2.C, IC2.21 (A10), IC2B.19 (A10), IC3.40 (A10), IC4.21 (A10), K1.B16 (16B)
A11: D1.C, IC2.23 (A11), IC2B.18 (A11), IC3.1 (A11), IC4.23 (A11), K1.B15 (15B)
A12: D3.C, IC2.2 (A12), IC2B.21 (A12), IC3.2 (A12), IC4.2 (A12), K1.B14 (14B)
A13: D5.C, IC2.26 (A13), IC3.3 (A13), IC4.26 (A13), JP3.2, K1.B13 (13B)
A14: D7.C, IC1.11 (A14), IC3.4 (A14), IC4.1 (A14), K1.B12 (12B)
A15: D8.C, IC1.18 (A15), IC3.5 (A15), K1.B11 (11B)
A'0: IC1.5 (A0), IC2.10 (A0), IC2B.8 (A0), RP6.7 (1)
A'1: IC1.4 (A1), IC2.9 (A1), IC2B.7 (A1), RP7.2
A'2: IC1.3 (A2), IC2.8 (A2), IC2B.6 (A2), RP7.3 (1)
A'3: IC1.36 (A3), IC2.7 (A3), IC2B.5 (A3), RP6.5 (1)
A'4: IC1.37 (A4), IC2.6 (A4), IC2B.4 (A4), RP6.3 (1)
A'5: IC1.38 (A5), IC2.5 (A5), IC2B.3 (A5), RP6.1
A'6: IC1.39 (A6), IC2.4 (A6), IC2B.2 (A6), RP7.5 (1)
A'7: IC1.1 (A7), IC2.3 (A7), IC2B.1 (A7), RP7.7 (1)
A'8: IC1.2 (A8), IC2.25 (A8), IC2B.23 (A8), RP7.9 (1)
CHNSW: K5.1
CLK: IC3.6 (CLK), R5.1, T2.C
D0: IC1.32 (D0), IC3.14 (D0), RP1.3, RP5.7 (1)
D1: IC1.30 (D1), IC3.15 (D1), RP1.2, RP4.7 (1)
D2: IC1.28 (D2), IC3.12 (D2), RP1.5, RP4.5 (1)
D3: IC1.26 (D3), IC3.8 (D3), RP1.8, RP4.3 (1)
D4: IC1.24 (D4), IC3.7 (D4), RP1.9, RP4.2
D5: IC1.23 (D5), IC3.9 (D5), RP1.7, RP5.2
D6: IC1.21 (D6), IC3.10 (D6), RP1.6, RP5.3 (1)
D7: IC1.19 (D7), IC3.13 (D7), RP1.4, RP5.6 (2)
D'0: IC2.11 (D0), IC2B.9 (D0), IC4.11 (D0), IC4B.14 (D0), K1.A4 (4A), RP5.8 (2)
D'1: IC2.12 (D1), IC2B.10 (D1), IC4.12 (D1), IC4B.13 (D1), K1.A5 (5A), RP4.8 (2)
D'2: IC2.13 (D2), IC2B.11 (D2), IC4.16 (D4), IC4A.11 (D3), K1.A6 (6A), RP4.6 (2)
D'3: IC2.15 (D3), IC2B.13 (D3), IC4.18 (D6), IC4A.13 (D1), K1.A9 (9A), RP4.4 (2)
D'4: IC2.16 (D4), IC2B.14 (D4), IC4.19 (D7), IC4A.14 (D0), K1.A10 (10A), RP4.1
D'5: IC2.17 (D5), IC2B.15 (D5), IC4.13 (D2), IC4B.12 (D2), K1.A8 (8A), RP5.1
D'6: IC2.18 (D6), IC2B.16 (D6), IC4.15 (D3), IC4B.11 (D3), K1.A7 (7A), RP5.4 (2)
D'7: IC2.19 (D7), IC2B.17 (D7), IC4.17 (D5), IC4A.12 (D2), K1.A1 (1A), RP5.5 (1)
GND: C2.2, C3.-, C4.2, C5.-, C8.2, C9.2, C11.2, IC1.34 (GND), IC2.14 (GND), IC2B.12 (GND), IC3.29 (GND), IC4.14 (GND), IC4A.9 (GND), IC4B.9 (GND), JP1.1, JP2.1, K1.B4 (4B), K1.B5 (5B), K2.2, K2.2', K3.2, K3.2', K4.2, K4.2', K5.7, K5.8, R3.1, R4.1, R27.1, R30.2, R31.1, R34.1, REG1.GND, S1.1, T2.E, X1.1
KBD0: IC1.33 (KBD0), KB1.P$1 (1), RP3.2
KBD1: IC1.31 (KBD1), KB1.P$2 (2), RP3.3
KBD2: IC1.29 (KBD2), KB1.P$3 (3), RP3.4
KBD3: IC1.27 (KBD3), KB1.P$4 (4), RP3.5
KBD4: IC1.25 (KBD4), KB1.P$5 (5), RP3.6
unnamed: IC1.12 (RAMCS), R2.1
unnamed: IC1.13 (ROMCS), R28.1
unnamed: C1.2, JP4.1, R1.2, T1.B
unnamed: C6.2, X1.2
unnamed: C6.1, IC1.35 (OSC), JP3.1, R4.2
unnamed: C7.2, R3.2, R6.2, T2.B
unnamed: IC2.27 (A14), JP1.2, R80.1
unnamed: D1.A, KB2.P$1 (1)
unnamed: D2.A, KB2.P$2 (2)
unnamed: D3.A, KB2.P$3 (3)
unnamed: D4.A, KB2.P$4 (4)
unnamed: D5.A, KB2.P$5 (5)
unnamed: D6.A, KB2.P$6 (6)
unnamed: D7.A, KB2.P$7 (7)
unnamed: D8.A, KB2.P$8 (8)
unnamed: C10.2, R33.1
unnamed: C12.2, R29.1
unnamed: IC2.1 (A15), JP2.2, R81.1
unnamed: D9.C, R32.2
unnamed: R35.1, T3.E
unnamed: R31.2, R32.1
unnamed: JP4.2, T3.C
PHI: C7.1, IC1.14 (CLK), K1.B6 (6B), R6.1
TAPEIN: IC1.20 (TAPE_IN), R33.2
TAPE_IN: C10.1, K3.1, K3.1', K5.3, R34.2
TAPE_OUT: C11.1, C12.1, K2.1, K2.1', R27.2
USA/UK: IC1.22 (USA/UK), K5.5, R30.1
VIDEO: D9.A, IC1.16 (TV/TAPE), K5.4, R29.2

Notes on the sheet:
R10
R12
R13
R11
R14
RP4/5 470
R26
R18
R19
R25
R24
R23
R20
R21
R22
RP6/7 1k
Modulator
vLA81

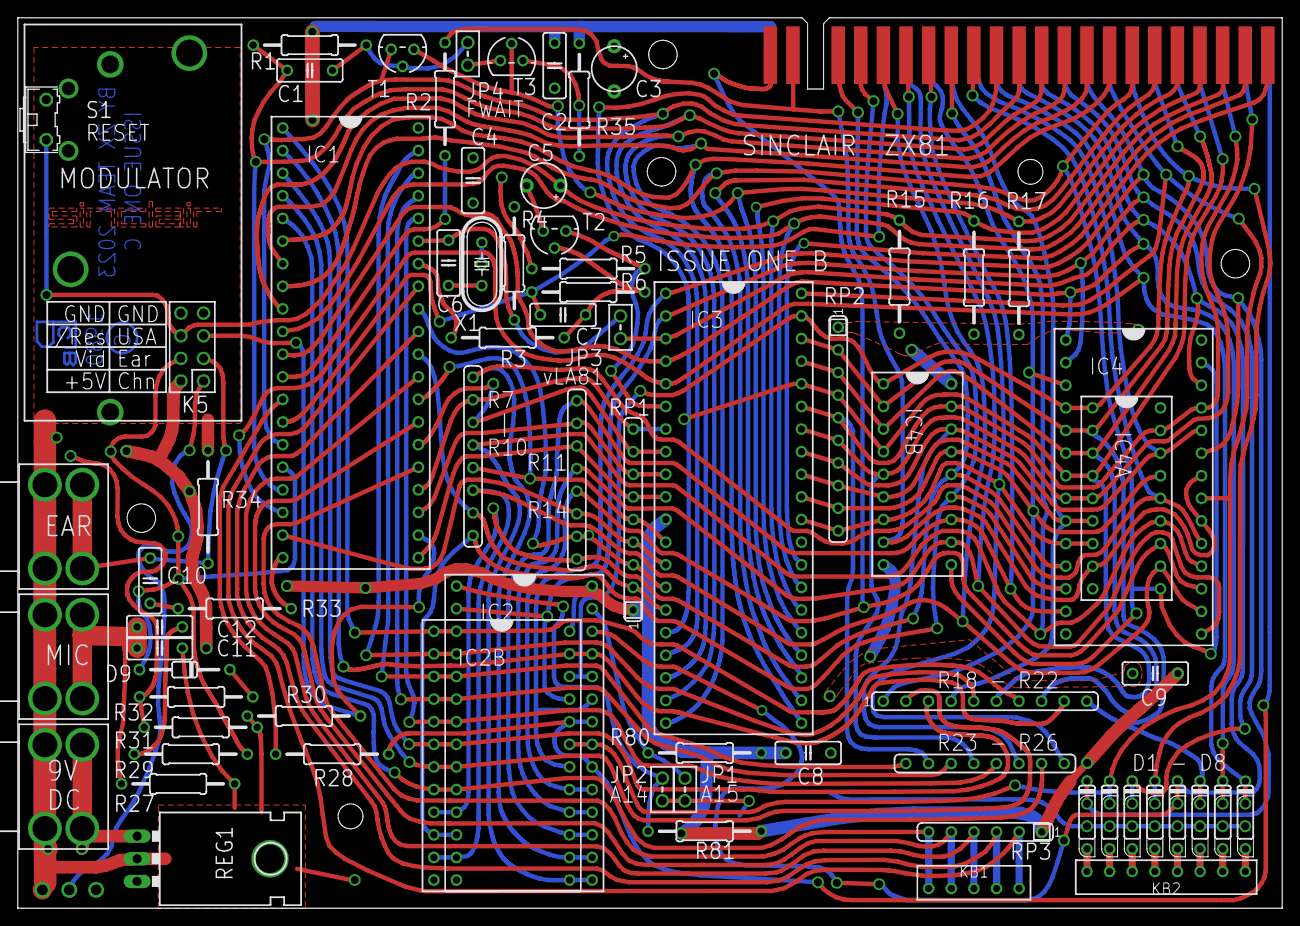
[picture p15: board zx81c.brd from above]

Board: 2 copper layers, 142.0 x 100.0 mm, 72 parts (0 on the bottom side), 92 nets.

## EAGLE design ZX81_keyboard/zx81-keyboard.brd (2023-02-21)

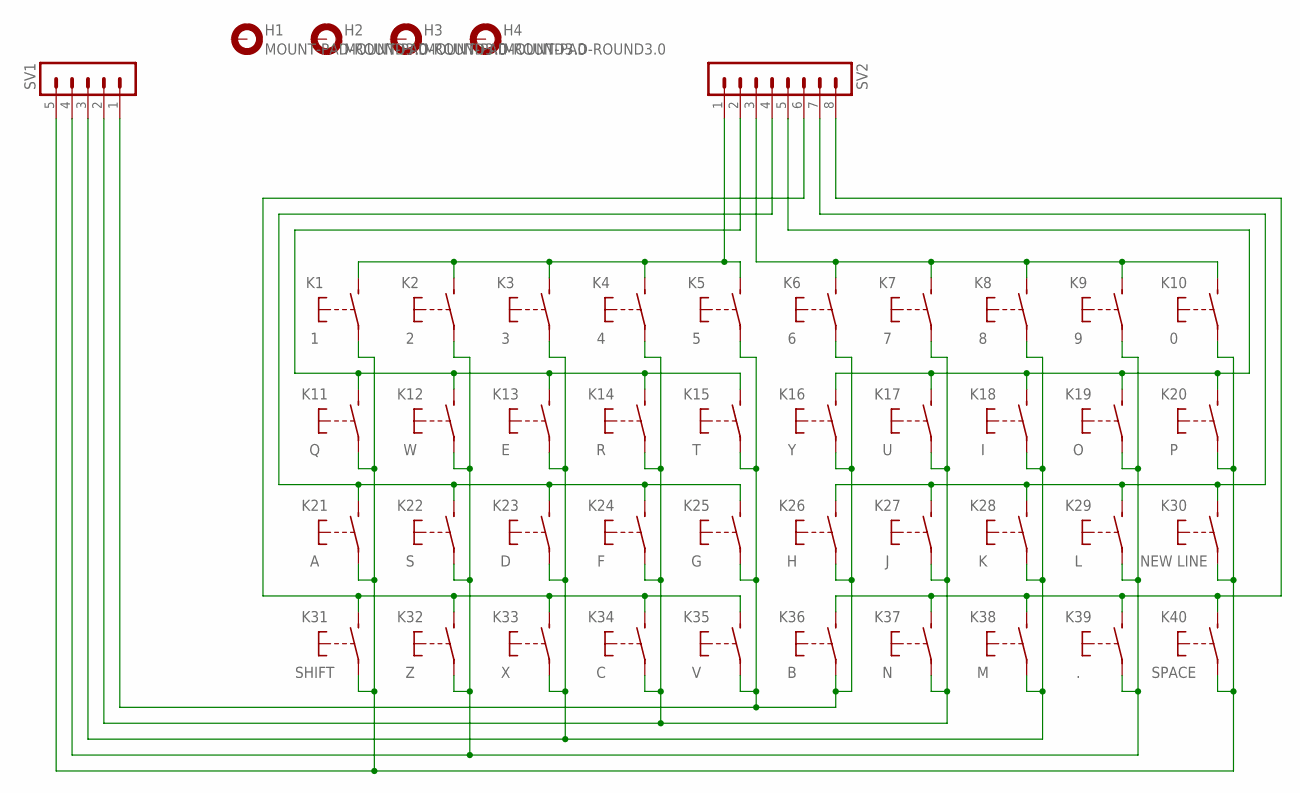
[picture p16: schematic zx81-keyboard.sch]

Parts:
H1, H2, H3, H4: MOUNT-PAD-ROUND3.0; 3,0-PAD
K1: 1; MARQUARTDT-6425
K2: 2; MARQUARTDT-6425
K3: 3; MARQUARTDT-6425
K4: 4; MARQUARTDT-6425
K5: 5; MARQUARTDT-6425
K6: 6; MARQUARTDT-6425
K7: 7; MARQUARTDT-6425
K8: 8; MARQUARTDT-6425
K9: 9; MARQUARTDT-6425
K10: 0; MARQUARTDT-6425
K11: Q; MARQUARTDT-6425
K12: W; MARQUARTDT-6425
K13: E; MARQUARTDT-6425
K14: R; MARQUARTDT-6425
K15: T; MARQUARTDT-6425
K16: Y; MARQUARTDT-6425
K17: U; MARQUARTDT-6425
K18: I; MARQUARTDT-6425
K19: O; MARQUARTDT-6425
K20: P; MARQUARTDT-6425
K21: A; MARQUARTDT-6425
K22: S; MARQUARTDT-6425
K23: D; MARQUARTDT-6425
K24: F; MARQUARTDT-6425
K25: G; MARQUARTDT-6425
K26: H; MARQUARTDT-6425
K27: J; MARQUARTDT-6425
K28: K; MARQUARTDT-6425
K29: L; MARQUARTDT-6425
K30: NEW LINE; MARQUARTDT-6425
K31: SHIFT; MARQUARTDT-6425
K32: Z; MARQUARTDT-6425
K33: X; MARQUARTDT-6425
K34: C; MARQUARTDT-6425
K35: V; MARQUARTDT-6425
K36: B; MARQUARTDT-6425
K37: N; MARQUARTDT-6425
K38: M; MARQUARTDT-6425
K39: .; MARQUARTDT-6425
K40: SPACE; MARQUARTDT-6425
SV1: MA05-1
SV2: MA08-1

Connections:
unnamed: K1.P$2 (S), K2.P$2 (S), K3.P$2 (S), K4.P$2 (S), K5.P$2 (S), SV2.1
unnamed: K6.P$2 (S), K7.P$2 (S), K8.P$2 (S), K9.P$2 (S), K10.P$2 (S), SV2.3
unnamed: K11.P$2 (S), K12.P$2 (S), K13.P$2 (S), K14.P$2 (S), K15.P$2 (S), SV2.2
unnamed: K21.P$2 (S), K22.P$2 (S), K23.P$2 (S), K24.P$2 (S), K25.P$2 (S), SV2.4
unnamed: K31.P$2 (S), K32.P$2 (S), K33.P$2 (S), K34.P$2 (S), K35.P$2 (S), SV2.6
unnamed: K16.P$2 (S), K17.P$2 (S), K18.P$2 (S), K19.P$2 (S), K20.P$2 (S), SV2.5
unnamed: K26.P$2 (S), K27.P$2 (S), K28.P$2 (S), K29.P$2 (S), K30.P$2 (S), SV2.7
unnamed: K36.P$2 (S), K37.P$2 (S), K38.P$2 (S), K39.P$2 (S), K40.P$2 (S), SV2.8
unnamed: K5.P$1, K6.P$1, K15.P$1, K16.P$1, K25.P$1, K26.P$1, K35.P$1, K36.P$1, SV1.1
unnamed: K4.P$1, K7.P$1, K14.P$1, K17.P$1, K24.P$1, K27.P$1, K34.P$1, K37.P$1, SV1.2
unnamed: K3.P$1, K8.P$1, K13.P$1, K18.P$1, K23.P$1, K28.P$1, K33.P$1, K38.P$1, SV1.3
unnamed: K2.P$1, K9.P$1, K12.P$1, K19.P$1, K22.P$1, K29.P$1, K32.P$1, K39.P$1, SV1.4
unnamed: K1.P$1, K10.P$1, K11.P$1, K20.P$1, K21.P$1, K30.P$1, K31.P$1, K40.P$1, SV1.5

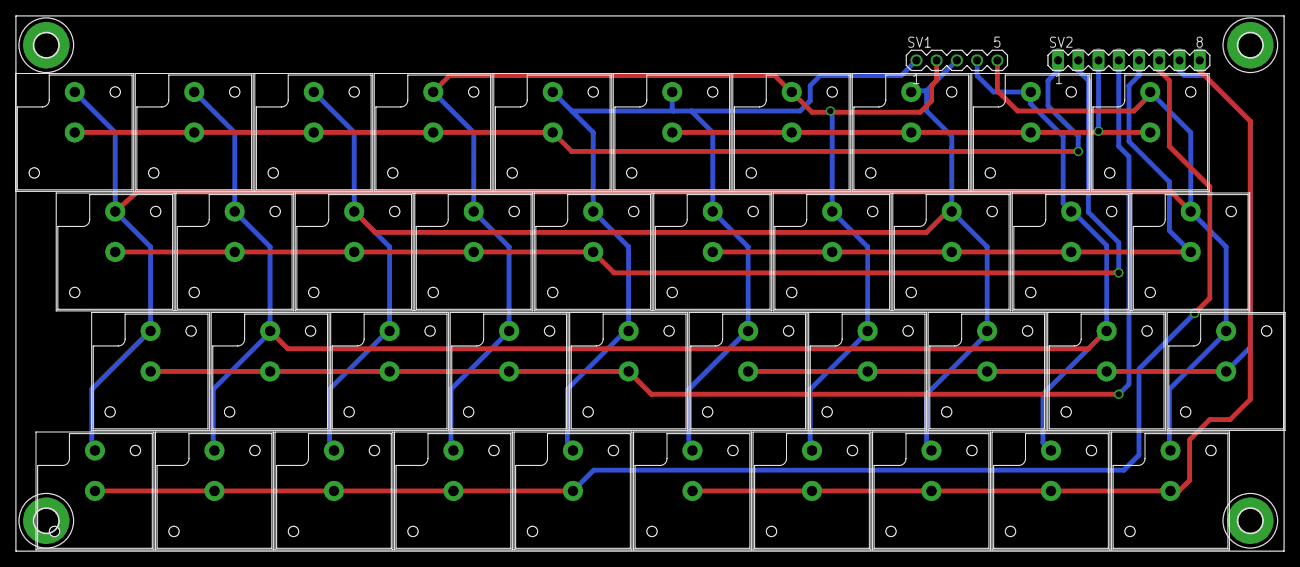
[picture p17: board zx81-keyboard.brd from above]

Board: 2 copper layers, 159.2 x 67.2 mm, 46 parts (0 on the bottom side), 13 nets.

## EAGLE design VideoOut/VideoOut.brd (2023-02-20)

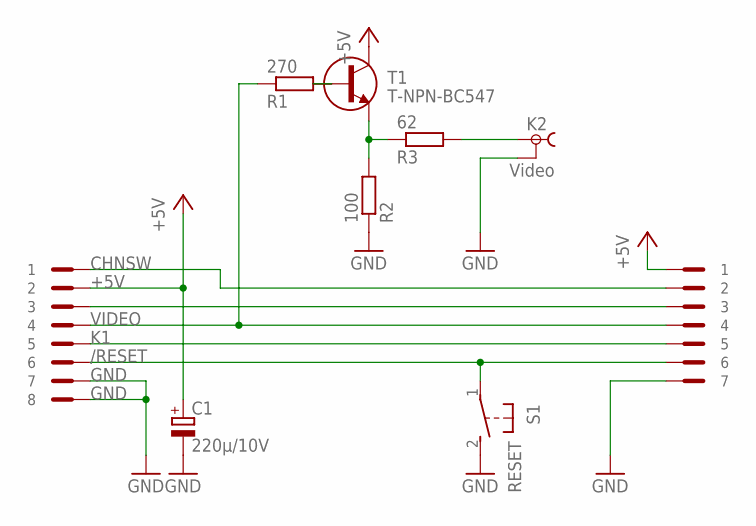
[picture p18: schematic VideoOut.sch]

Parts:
C1: 220µ/10V; E2,5-6
K2: Video; TOBU3
K3: PINHEAD-1X7; PINHEAD1X7
K6: PINHEAD-2X4; PINHEAD2X4
R1: 270; R207/10
R2: 100; R207/10
R3: 62; R207/10
S1: RESET; B3F-31XX
T1: T-NPN-BC547; TO92

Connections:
+5V: C1.+, K3.1, K6.2, T1.C
/RESET: K3.6, K6.6, S1.1
CHNSW: K3.2, K6.1
GND: C1.-, K2.2, K2.2@1 (2), K2.2@2 (2), K3.7, K6.7, K6.8, R2.1, S1.2 (S)
K1: K3.5, K6.5
unnamed: K3.3, K6.3
unnamed: R1.2, T1.B
unnamed: R2.2, R3.1, T1.E
unnamed: K2.1, R3.2
VIDEO: K3.4, K6.4, R1.1

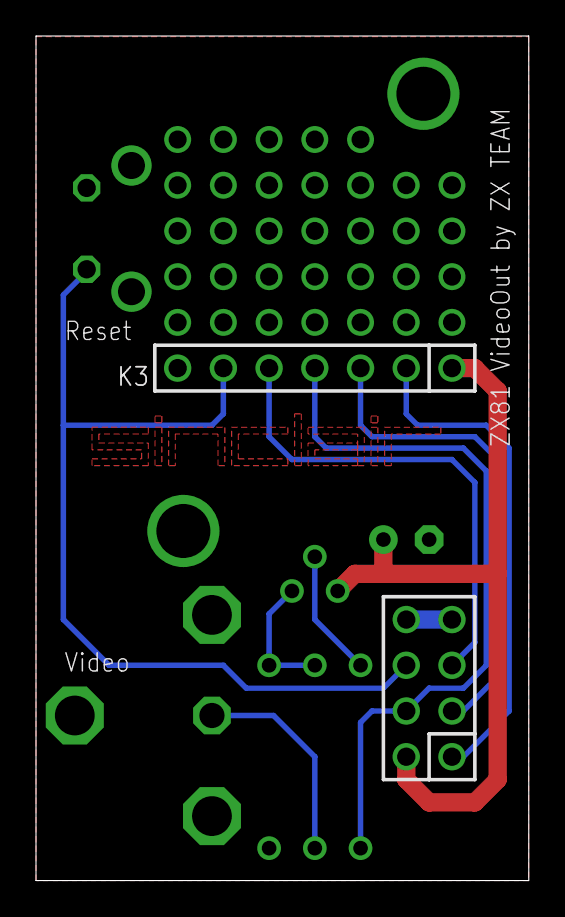
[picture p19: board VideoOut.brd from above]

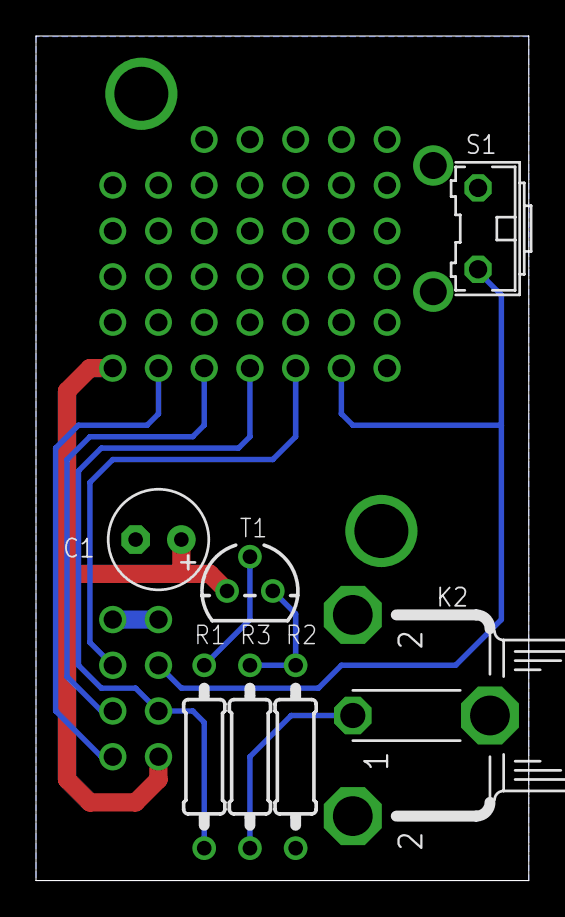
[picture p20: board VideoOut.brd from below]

Board: 2 copper layers, 27.4 x 46.9 mm, 9 parts (7 on the bottom side), 10 nets.

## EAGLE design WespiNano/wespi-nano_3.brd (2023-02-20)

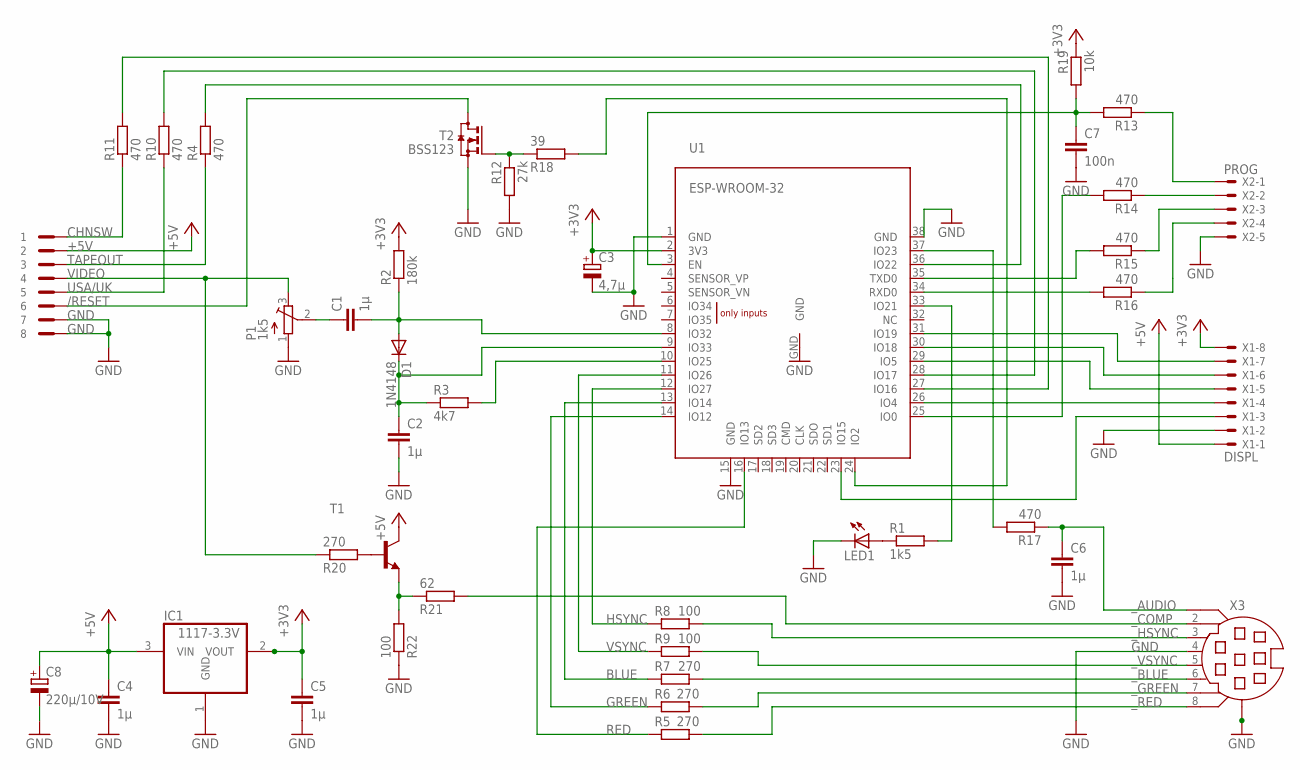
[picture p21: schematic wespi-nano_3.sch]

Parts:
C1, C2, C4, C5, C6: 1µ; C0805
C3: 4,7µ; 153CLV-0405
C7: 100n; C0805
C8: 220µ/10V; E2,5-6
D1: 1N4148; SOD-123_MINI-SMA
IC1: 1117-3.3V; SOT223
K6: PINHEAD-2X4; PINHEAD2X4
LED1: LEDSML0805; SML0805
P1: 1k5; 3223G
R1: 1k5; R0805
R2: 180k; R0805
R3: 4k7; R0805
R4, R10, R11, R13, R14, R15, R16, R17: 470; R0805
R5, R6, R7, R20: 270; R0805
R8, R9, R22: 100; R0805
R12: 27k; R0805
R18: 39; R0805
R19: 10k; R0805
R21: 62; R0805
T1: BC847-NPN-SOT23-BEC; SOT23-BEC
T2: BSS123; SOT23
U1: ESP-WROOM-32
X1: DISPL; 53047-08
X2: PROG; 53047-05
X3: MINI-DIN-8

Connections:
+3V3: C3.+, C5.1, IC1.2 (VOUT), IC1.4 (VOUT1), R2.2, R19.1, U1.2 (3V3), X1.8
+5V: C4.1, C8.+, IC1.3 (VIN), K6.2, T1.C, X1.1
/RESET: K6.6, T2.3 (D)
BLUE: R7.1, U1.13 (IO14)
BOOT0: R14.1, X2.2
CHNSW: K6.1, R11.1
GND: C2.2, C3.-, C4.2, C5.2, C6.2, C7.2, C8.-, IC1.1 (GND), K6.7, K6.8, LED1.C, P1.1 (A), R12.2, R22.1, T2.2 (S), U1.1 (GND), U1.15 (GND), U1.38 (GND), U1.GND, X1.2, X2.5, X3.4, X3.G (G1), X3.G1 (G2), X3.G2 (G3)
GREEN: R6.1, U1.14 (IO12)
HSYNC: R8.1, U1.12 (IO27)
IO0: R14.2, U1.25 (IO0)
unnamed: K6.3, R4.1
unnamed: U1.23 (IO15), X1.3
unnamed: C1.2, D1.A, R2.1, U1.8 (IO32)
unnamed: C2.1, D1.C, R3.1, U1.9 (IO33)
unnamed: R3.2, U1.10 (IO25)
unnamed: R20.2, T1.B
unnamed: R21.1, R22.2, T1.E
unnamed: LED1.A, R1.1
unnamed: C1.1, P1.2 (S)
unnamed: R1.2, U1.33 (IO21)
unnamed: R18.2, U1.24 (IO2)
unnamed: U1.26 (IO4), X1.4
unnamed: R10.2, U1.28 (IO17)
unnamed: R11.2, U1.27 (IO16)
unnamed: U1.29 (IO5), X1.5
unnamed: U1.30 (IO18), X1.6
unnamed: U1.31 (IO19), X1.7
unnamed: R12.1, R18.1, T2.1 (G)
unnamed: R17.2, U1.37 (IO23)
RED: R5.1, U1.16 (IO13)
RESET: C7.1, R13.2, R19.2, U1.3 (EN)
RXD0: R16.2, U1.34 (RXD0)
TAPEOUT: R4.2, U1.36 (IO22)
TXD0: R15.2, U1.35 (TXD0)
USA/UK: K6.5, R10.1
VIDEO: K6.4, P1.3 (E), R20.1
VSYNC: R9.1, U1.11 (IO26)
_AUDIO: C6.1, R17.1, X3.1
_BLUE: R7.2, X3.6
_COMP: R21.2, X3.2
_GREEN: R6.2, X3.7
_HSYNC: R8.2, X3.3
_RED: R5.2, X3.8
_RESET: R13.1, X2.1
_RXD: R16.1, X2.4
_TXD: R15.1, X2.3
_VSYNC: R9.2, X3.5

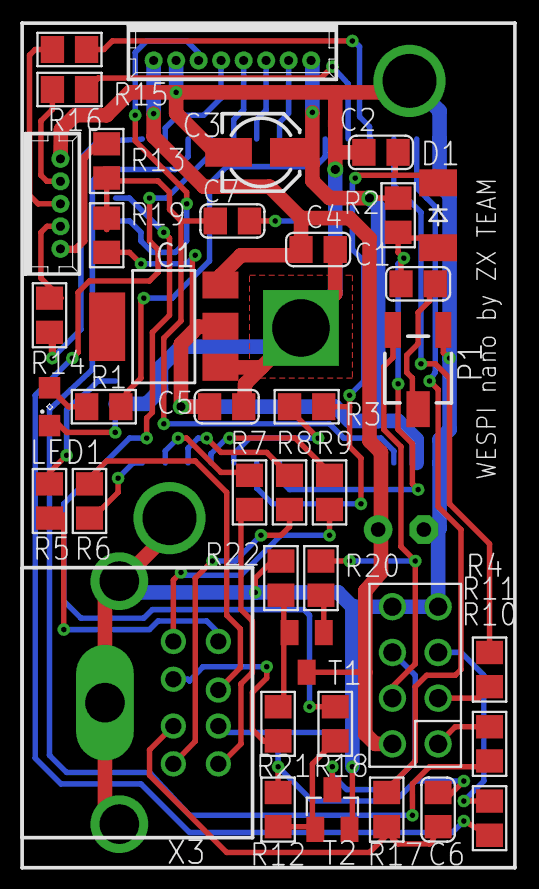
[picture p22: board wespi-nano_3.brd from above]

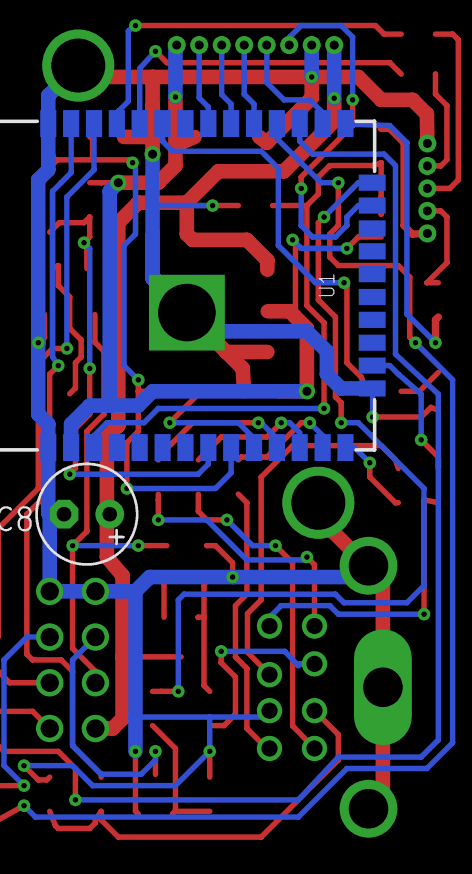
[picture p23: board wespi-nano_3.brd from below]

Board: 2 copper layers, 41 parts (2 on the bottom side), 47 nets.

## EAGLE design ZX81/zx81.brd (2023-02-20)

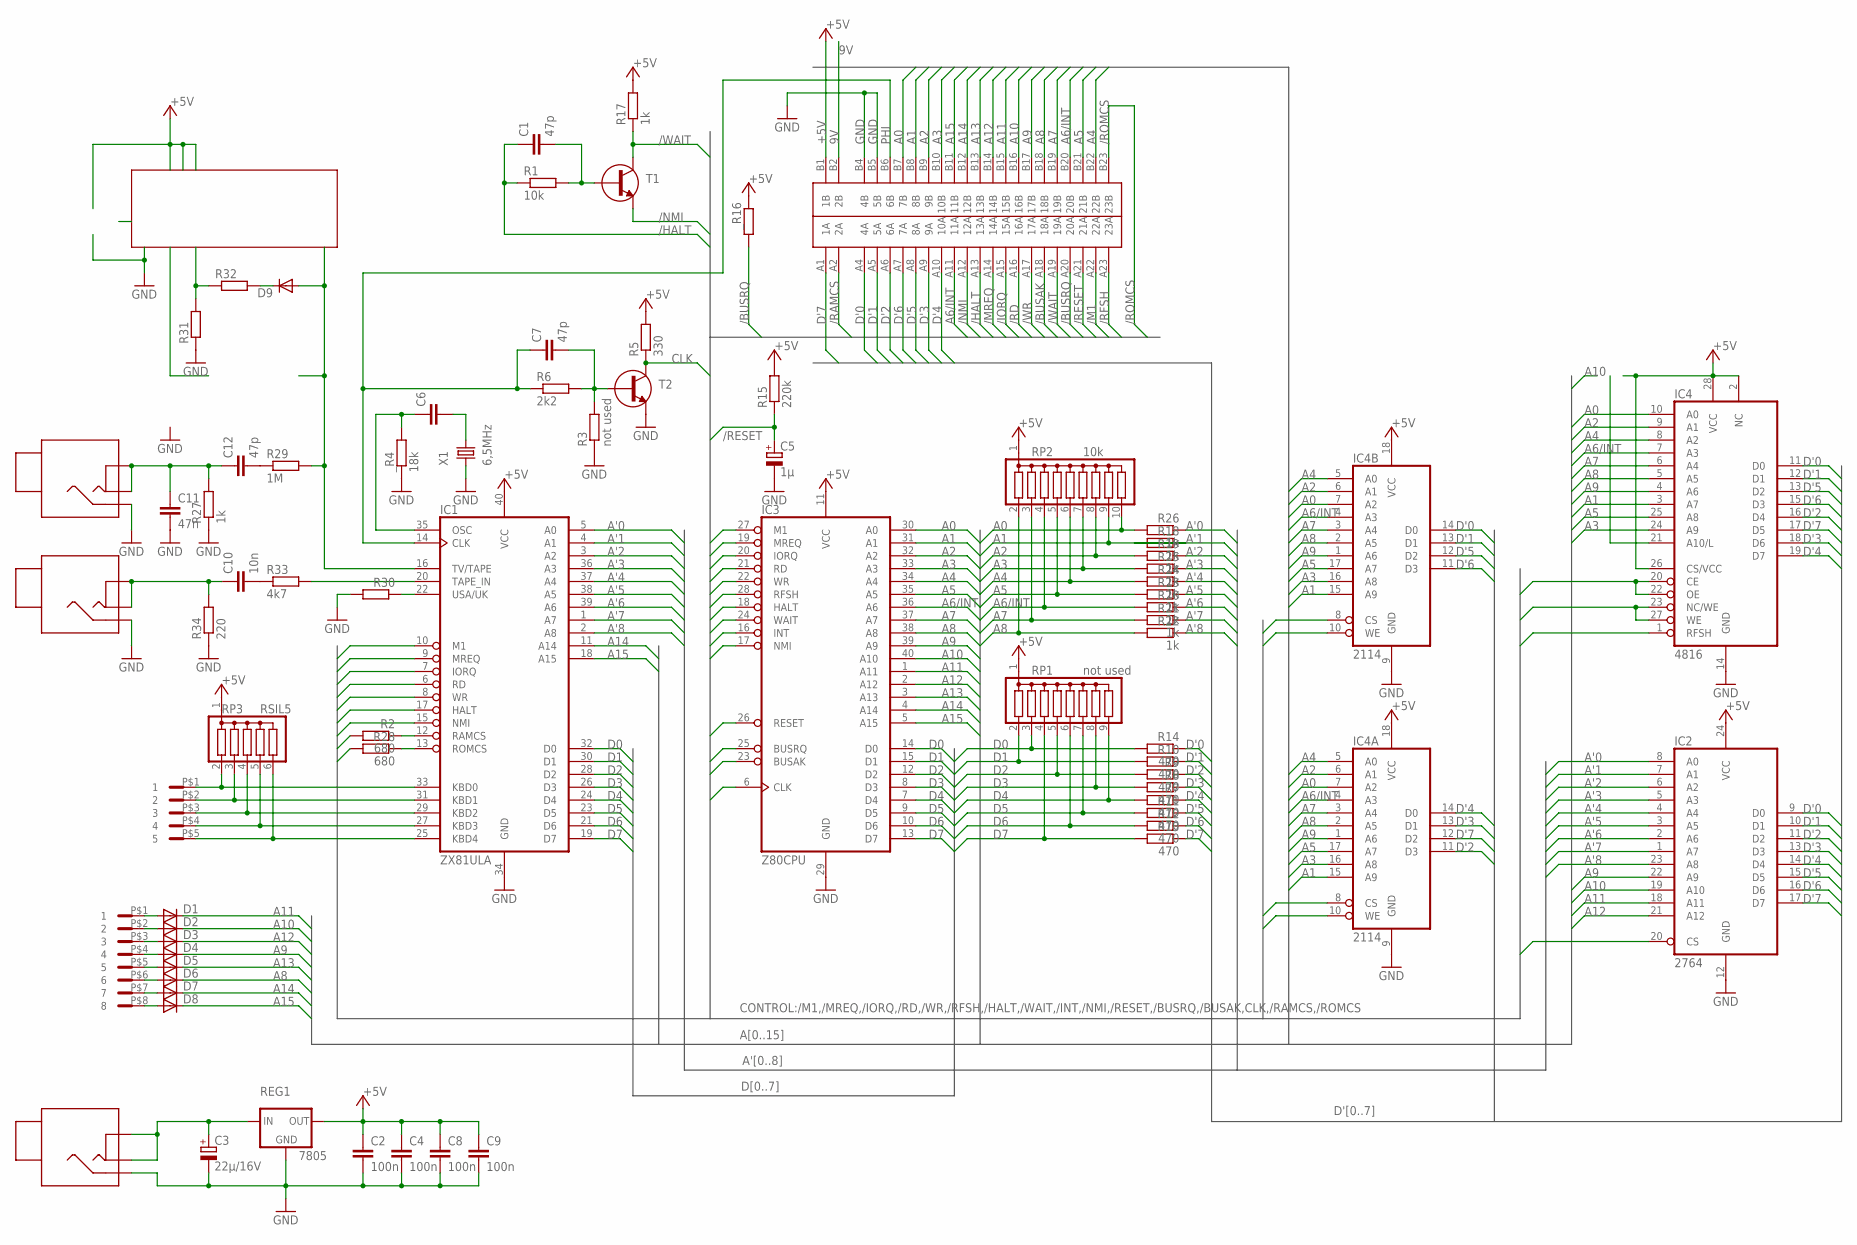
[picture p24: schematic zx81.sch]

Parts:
C1, C7, C12: 47p; C025-025X050
C2, C4, C8, C9: 100n; C025-025X050
C3: 22µ/16V; E5-5
C5: 1µ; E3,8-5
C6: C; C025-025X050
C10: 10n; C025-025X050
C11: 47n; C025-025X050
D1, D2, D3, D4, D5, D6, D7, D8: DIODED10; D10
D9: DIODED15; D15
IC1: ZX81ULA; DIL40
IC2: 2764; DIL24
IC3: Z80CPU; DIL40
IC4: 4816; DIL28
IC4A, IC4B: 2114; DIL18
K1: ZX81CONN; ZX81CON
K2: MIC; ZXKLINKE
K3: EAR; ZXKLINKE
K4: DCIN; ZXKLINKE
KB1: ZXKBD5CON; ZXKDB5
KB2: ZXKBD8CON; ZXKBD8
R1: 10k; R207/12
R2, R28: 680; R207/12
R3: not used; R207/12
R5: 330; R207/12
R6: 2k2; R207/12
R7, R8, R9, R10, R11, R12, R13, R14: 470; RV
R15: 220k; R207/12
R17, R27: 1k; R207/12
R18, R19, R20, R21, R22, R23, R24, R25, R26: 1k; RV
R29: 1M; R207/12
R30, R31, R32: RR207/12; R207/12
R33: 4k7; R207/12
R34: 220; R207/12
REG1: 7805; 78XXL
RP1: not used; SIL9
RP2: 10k; SIL10
RP3: RSIL5; SIL6
T1, T2: T-NPN-ZTX313TO92FLAT; TO92FLAT
X1: 6,5MHz; HC49
_R4: 18k; R207/12
_R16: RR207/12; R207/12

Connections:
9V: K1.B2 (2B)
+5V: C2.1, C4.1, C8.1, C9.1, IC1.40 (VCC), IC2.24 (VCC), IC3.11 (VCC), IC4.2 (NC), IC4.26 (CS/VCC), IC4.28 (VCC), IC4A.18 (VCC), IC4B.18 (VCC), K1.B1 (1B), R5.2, R15.2, R17.2, REG1.OUT, RP1.1, RP2.1, RP3.1, _R16.1
/BUSAK: IC3.23 (BUSAK), K1.A18 (18A)
/BUSRQ: IC3.25 (BUSRQ), K1.A20 (20A), _R16.2
/HALT: C1.1, IC1.17 (HALT), IC3.18 (HALT), K1.A13 (13A), R1.1
/IORQ: IC1.7 (IORQ), IC3.20 (IORQ), K1.A15 (15A)
/M1: IC1.10 (M1), IC3.27 (M1), K1.A22 (22A)
/MREQ: IC1.9 (MREQ), IC3.19 (MREQ), K1.A14 (14A)
/NMI: IC1.15 (NMI), IC3.17 (NMI), K1.A12 (12A), T1.3 (E)
/RAMCS: IC4.20 (CE), IC4.22 (OE), IC4A.8 (CS), IC4B.8 (CS), K1.A2 (2A), R2.2
/RD: IC1.6 (RD), IC3.21 (RD), K1.A16 (16A)
/RESET: C5.+, IC3.26 (RESET), K1.A21 (21A), R15.1
/RFSH: IC3.28 (RFSH), IC4.1 (RFSH), K1.A23 (23A)
/ROMCS: IC2.20 (CS), K1.B23 (23B), R28.2
/WAIT: IC3.24 (WAIT), K1.A19 (19A), R17.1, T1.2 (C)
/WR: IC1.8 (WR), IC3.22 (WR), IC4.23 (NC/WE), IC4.27 (WE), IC4A.10 (WE), IC4B.10 (WE), K1.A17 (17A)
A0: IC3.30 (A0), IC4.10 (A0), IC4A.7 (A2), IC4B.7 (A2), K1.B7 (7B), R26.2, RP2.10
A1: IC3.31 (A1), IC4.3 (A7), IC4A.15 (A9), IC4B.15 (A9), K1.B8 (8B), R18.1, RP2.9
A2: IC3.32 (A2), IC4.9 (A1), IC4A.6 (A1), IC4B.6 (A1), K1.B9 (9B), R19.2, RP2.8
A3: IC3.33 (A3), IC4.24 (A9), IC4A.16 (A8), IC4B.16 (A8), K1.B10 (10B), R25.2, RP2.7
A4: IC3.34 (A4), IC4.8 (A2), IC4A.5 (A0), IC4B.5 (A0), K1.B22 (22B), R24.2, RP2.6
A5: IC3.35 (A5), IC4.25 (A8), IC4A.17 (A7), IC4B.17 (A7), K1.B21 (21B), R23.2, RP2.5
A6/INT: IC3.16 (INT), IC3.36 (A6), IC4.7 (A3), IC4A.4 (A3), IC4B.4 (A3), K1.A11 (11A), K1.B20 (20B), R20.2, RP2.4
A7: IC3.37 (A7), IC4.6 (A4), IC4A.3 (A4), IC4B.3 (A4), K1.B19 (19B), R21.2, RP2.3
A8: D6.C, IC3.38 (A8), IC4.5 (A5), IC4A.2 (A5), IC4B.2 (A5), K1.B18 (18B), R22.2, RP2.2
A9: D4.C, IC2.22 (A9), IC3.39 (A9), IC4.4 (A6), IC4A.1 (A6), IC4B.1 (A6), K1.B17 (17B)
A10: D2.C, IC2.19 (A10), IC3.40 (A10), K1.B16 (16B)
A10/L: IC4.21 (A10/L)
A11: D1.C, IC2.18 (A11), IC3.1 (A11), K1.B15 (15B)
A12: D3.C, IC2.21 (A12), IC3.2 (A12), K1.B14 (14B)
A13: D5.C, IC3.3 (A13), K1.B13 (13B)
A14: D7.C, IC1.11 (A14), IC3.4 (A14), K1.B12 (12B)
A15: D8.C, IC1.18 (A15), IC3.5 (A15), K1.B11 (11B)
A'0: IC1.5 (A0), IC2.8 (A0), R26.1
A'1: IC1.4 (A1), IC2.7 (A1), R18.2
A'2: IC1.3 (A2), IC2.6 (A2), R19.1
A'3: IC1.36 (A3), IC2.5 (A3), R25.1
A'4: IC1.37 (A4), IC2.4 (A4), R24.1
A'5: IC1.38 (A5), IC2.3 (A5), R23.1
A'6: IC1.39 (A6), IC2.2 (A6), R20.1
A'7: IC1.1 (A7), IC2.1 (A7), R21.1
A'8: IC1.2 (A8), IC2.23 (A8), R22.1
CLK: IC3.6 (CLK), R5.1, T2.2 (C)
D0: IC1.32 (D0), IC3.14 (D0), R14.2, RP1.3
D1: IC1.30 (D1), IC3.15 (D1), R10.2, RP1.2
D2: IC1.28 (D2), IC3.12 (D2), R9.2, RP1.5
D3: IC1.26 (D3), IC3.8 (D3), R8.2, RP1.8
D4: IC1.24 (D4), IC3.7 (D4), R7.2, RP1.9
D5: IC1.23 (D5), IC3.9 (D5), R11.2, RP1.7
D6: IC1.21 (D6), IC3.10 (D6), R12.2, RP1.6
D7: IC1.19 (D7), IC3.13 (D7), R13.2, RP1.4
D'0: IC2.9 (D0), IC4.11 (D0), IC4B.14 (D0), K1.A4 (4A), R14.1
D'1: IC2.10 (D1), IC4.12 (D1), IC4B.13 (D1), K1.A5 (5A), R10.1
D'2: IC2.11 (D2), IC4.16 (D4), IC4A.11 (D3), K1.A6 (6A), R9.1
D'3: IC2.13 (D3), IC4.18 (D6), IC4A.13 (D1), K1.A9 (9A), R8.1
D'4: IC2.14 (D4), IC4.19 (D7), IC4A.14 (D0), K1.A10 (10A), R7.1
D'5: IC2.15 (D5), IC4.13 (D2), IC4B.12 (D2), K1.A8 (8A), R11.1
D'6: IC2.16 (D6), IC4.15 (D3), IC4B.11 (D3), K1.A7 (7A), R12.1
D'7: IC2.17 (D7), IC4.17 (D5), IC4A.12 (D2), K1.A1 (1A), R13.1
GND: C2.2, C3.-, C4.2, C5.-, C8.2, C9.2, C11.2, IC1.34 (GND), IC2.12 (GND), IC3.29 (GND), IC4.14 (GND), IC4A.9 (GND), IC4B.9 (GND), K1.B4 (4B), K1.B5 (5B), K2.2, K3.2, K4.2, R3.1, R27.1, R30.2, R31.1, R34.1, REG1.GND, T2.3 (E), X1.1, _R4.1
KBD0: IC1.33 (KBD0), KB1.P$1 (1), RP3.2
KBD1: IC1.31 (KBD1), KB1.P$2 (2), RP3.3
KBD2: IC1.29 (KBD2), KB1.P$3 (3), RP3.4
KBD3: IC1.27 (KBD3), KB1.P$4 (4), RP3.5
KBD4: IC1.25 (KBD4), KB1.P$5 (5), RP3.6
unnamed: IC1.12 (RAMCS), R2.1
unnamed: IC1.13 (ROMCS), R28.1
unnamed: C1.2, R1.2, T1.1 (B)
unnamed: C6.2, X1.2
unnamed: C6.1, IC1.35 (OSC), _R4.2
unnamed: C7.2, R3.2, R6.2, T2.1 (B)
unnamed: C3.+, K4.1, K4.1', REG1.IN
unnamed: D1.A, KB2.P$1 (1)
unnamed: D2.A, KB2.P$2 (2)
unnamed: D3.A, KB2.P$3 (3)
unnamed: D4.A, KB2.P$4 (4)
unnamed: D5.A, KB2.P$5 (5)
unnamed: D6.A, KB2.P$6 (6)
unnamed: D7.A, KB2.P$7 (7)
unnamed: D8.A, KB2.P$8 (8)
unnamed: C10.2, R33.1
unnamed: C12.2, R29.1
unnamed: D9.C, R32.2
unnamed: R31.2, R32.1
PHI: C7.1, IC1.14 (CLK), K1.B6 (6B), R6.1
TAPEIN: IC1.20 (TAPE_IN), R33.2
TAPE_IN: C10.1, K3.1, K3.1', R34.2
TAPE_OUT: C11.1, C12.1, K2.1, K2.1', R27.2
USA/UK: IC1.22 (USA/UK), R30.1
VIDEO: D9.A, IC1.16 (TV/TAPE), R29.2

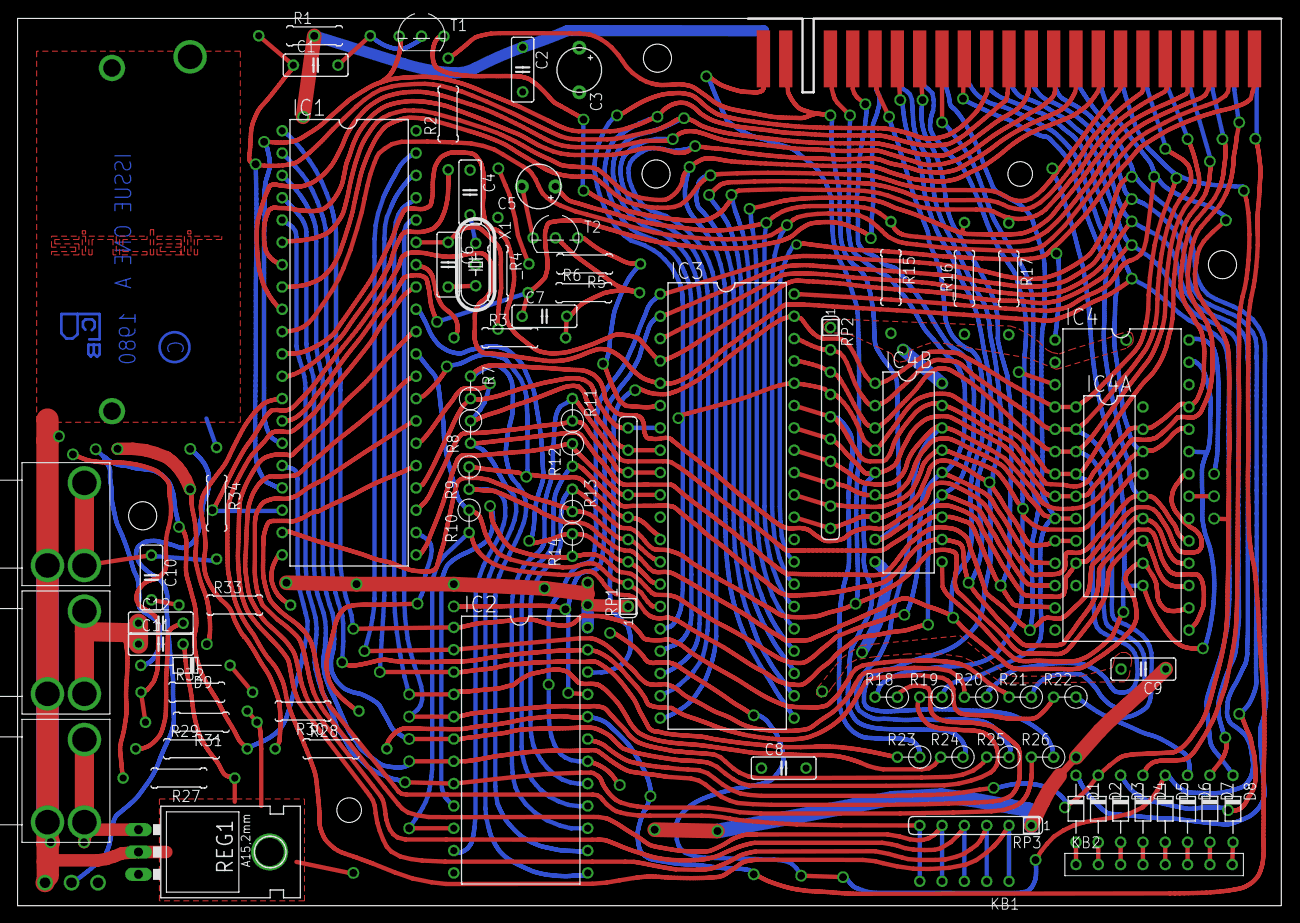
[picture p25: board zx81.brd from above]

Board: 2 copper layers, 143.9 x 101.0 mm, 74 parts (0 on the bottom side), 88 nets.
